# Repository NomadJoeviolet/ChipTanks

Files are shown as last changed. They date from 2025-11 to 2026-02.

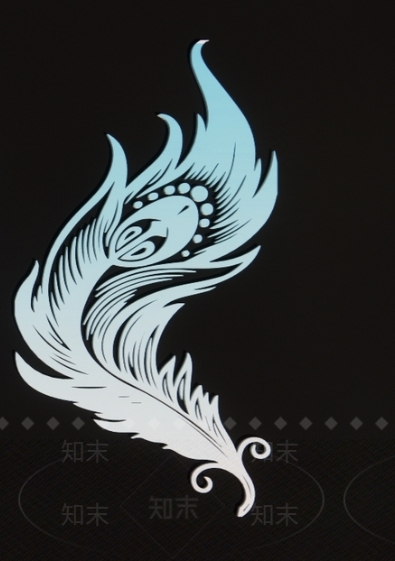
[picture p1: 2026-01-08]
ChipTanksPic/Phoenix.jpg

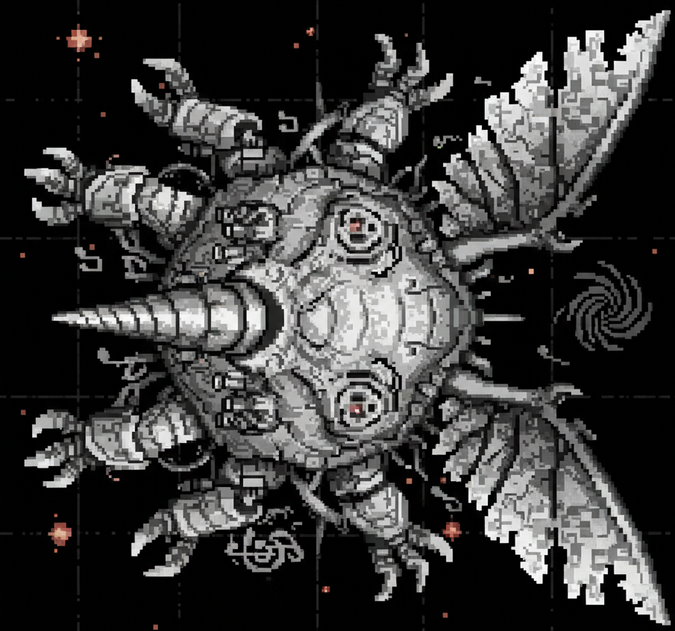
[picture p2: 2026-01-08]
ChipTanksPic/Hundun.png

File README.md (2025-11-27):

# ChipTanks

STM32F103 上的 128×64 OLED 迷你射击游戏。C/C++ 混编，FreeRTOS 驱动，使用 ETL（Embedded Template Library）以适配嵌入式资源约束。

项目总结博客：[ChipTanks-基于C&C++混编的STM32OLED迷你游戏掌机个人项目开发](https://nomadjoeviolet.github.io/p/chiptanks-%E5%9F%BA%E4%BA%8Ecc-%E6%B7%B7%E7%BC%96%E7%9A%84stm32oled%E8%BF%B7%E4%BD%A0%E6%B8%B8%E6%88%8F%E6%8E%8C%E6%9C%BA%E4%B8%AA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)

## 特性概览
- Roguelike 构筑：关卡/波次推进，中场与过关选卡，增益直接作用玩家数据。
- 实体系统：角色与子弹分层，统一管理器调度（行动 → 状态 → 清理 → 渲染）。
- 计时与节奏：用统一步长控制冷却、热量、回血、过场窗口，确定性强。
- 资源友好：固定容量容器（etl::vector），全局 new/delete 重定向至 FreeRTOS 堆。

## 目录结构（摘）
- App/
  - gameEntityManager.hpp（实体管理器）
  - gamePerkCardManager.hpp（选卡/增益管理器）
  - gameProgressManager.hpp（关卡/波次/Boss/过场）
  - threads.cpp（渲染/输入/控制三线程）
  - Bullet/（子弹抽象与实现）
  - Role/（玩家/敌人/基类实现）
  - Data/basicData.hpp（核心数据结构）
- Core/（HAL、FreeRTOS glue 等）
- Drivers/（STM32 HAL、CMSIS）
- Lib/etl/（Embedded Template Library）
- Middlewares/Third_Party/FreeRTOS/
- cmake/（ARM 工具链文件等）

## 构建
前置：
- ARM 交叉工具链（arm-none-eabi-gcc 系）
- CMake（建议 3.20+）与 Ninja（可选）

示例（PowerShell）：
```powershell
# Release 构建
cmake -S . -B build/Release -G Ninja `
  -DCMAKE_TOOLCHAIN_FILE=cmake/gcc-arm-none-eabi.cmake `
  -DCMAKE_BUILD_TYPE=Release
cmake --build build/Release

# Debug 构建
cmake -S . -B build/Debug -G Ninja `
  -DCMAKE_TOOLCHAIN_FILE=cmake/gcc-arm-none-eabi.cmake `
  -DCMAKE_BUILD_TYPE=Debug
cmake --build build/Debug
```
如使用 IDE/调试器：仓库根目录含有若干 .jdebug 文件，可按本地调试环境导入使用。

## 烧录与运行
- 烧录方式取决于本地工具链（如 J-Link、OpenOCD、IDE 内置烧录）。
- 上电后，显示开场动画 → 进入第一关。玩家存活则推进波次/关卡；清场时触发选卡或进入 Boss/通关流程。

## 运行机制
- 线程
  - 渲染线程：根据状态绘制开场/通关/Boss/选卡/战斗界面，控制刷新节奏。
  - 输入线程：按键扫描；战斗态写入玩家移动；选卡态移动光标并确认选择。
  - 控制线程：推进进度（清场→波次/关卡/选卡），调度实体行动/状态，清理无效对象。
- 管理器
  - 实体管理器：
    - addRole/addBullet，updateAllRolesActions/State，updateAllBulletsActions/State
    - 碰撞（AABB）与范围伤害，经验结算与资源回收，drawAllRoles/Bullets
  - 进度管理器：
    - 清场判定（场上仅玩家）→ 波次/关卡推进 → 敌人阵型或 Boss 生成 → 过场与展示
  - 卡片管理器：
    - 初始化仓库、随机抽取、应用所选、未选回库、绘制选卡界面

## 玩法与数值（摘）
- 子弹类型：
  - 普通弹：基础直击伤害。
  - 火球弹：直击后附带圆形范围溅射。
  - 闪电链：穿透，按伤害倍率与常数加成计算。
- 计时器：
  - 射击冷却：归零前禁射；步长与速度决定射速。
  - 热量系统：每次开火升温，周期降温；过热禁射。
  - 回血：累计到阈值离散恢复，直至上限。

## 开发要点
- FreeRTOS 头文件顺序：需先包含 FreeRTOS.h，再包含 task.h（管理器中已按此顺序）。
- 全局 new/delete 重载：见 App/reload_new_delete.cpp（路由至 pvPortMalloc/vPortFree）。
- 容量上限：角色最多 20，子弹最多 100；add 失败时需释放临时对象。
- 清场判定：当前以“容器仅剩玩家”作为清场条件；如引入友军/召唤物，建议改为“无敌方单位”。
- 子弹尺寸：构造子弹时需确保图片与尺寸有效，避免空指针读取尺寸。

## 致谢
- STM32 HAL/FreeRTOS、ETL 以及开源社区相关资源。

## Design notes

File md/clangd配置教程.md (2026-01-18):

# clangd 配置教程（保姆级）

> 适用场景：STM32/嵌入式交叉编译（ARM GCC）、C/C++ 混编、第三方库（如 ETL）大量头文件、Windows + VS Code + clangd 语义分析。
>
> 目标：让 clangd 的“跳转/补全/诊断”与真实编译一致，消灭 `string.h not found`、`type_traits not found`、`Unsupported option '-mcpu=' for target x86_64...`、`unknown type name 'namespace'` 这类“能编译但 clangd 报错”的假红线。

---

## 1. 先搞清楚 clangd 在做什么（核心概念）

clangd 本质是在**模拟编译器**来解析你的代码。

它需要两类信息：

1. **每个源文件实际的编译参数**（include 路径、宏、`-mcpu`、`-std` 等）
   - 最佳来源：`compile_commands.json`（由 CMake/Ninja/Bear 等生成）
2. **工具链自带的系统头/标准库头路径**（如 ARM GCC 的 newlib、libstdc++ 头）
   - clangd 自己猜不准，必须让它能“问”到你的交叉编译器（query-driver）。

如果 clangd 拿不到正确配置，它会退回默认目标（Windows 下常见是 `x86_64-pc-windows-msvc`），然后你就会看到很多“离谱”的报错。

---

## 2. 安装与基本使用（VS Code）

### 2.1 安装 clangd

建议使用：VS Code 扩展 **clangd**（LLVM 官方 clangd 语言服务器的 VS Code 客户端）。

重要提醒：
- 如果你同时装了 MS C/C++ 扩展（cpptools），要注意它可能会提供另一套 IntelliSense。
- 想完全用 clangd：通常做法是**禁用 cpptools 的 IntelliSense**，只保留它的调试/构建能力（可选）。

### 2.2 “怎么确认 clangd 在工作？”

打开 VS Code：
- “输出(OUTPUT)”面板右上角下拉选择 **clangd**
- 你能看到它为哪个文件“Build preamble / publishDiagnostics”等日志。

---

## 3. 必须准备：compile_commands.json

### 3.1 为什么必须要它？

它是“clangd 和真实编译一致”的根基。

没有它，你必须手写一堆 `-I`、`-D`、`-mcpu`，很难维护。

### 3.2 在本项目里它在哪里？

你的工程构建目录里有：
- `build/Debug/compile_commands.json`
- `build/Release/compile_commands.json`

### 3.3 典型坑：Debug/Release 两套数据库

clangd 一次只能用一个 `--compile-commands-dir`。

- 用 Debug 就配 Debug
- 用 Release 就配 Release

---

## 4. VS Code 里配置 clangd（最关键）

clangd 的“启动参数”是最关键入口：`clangd.arguments`。

在项目的：`.vscode/settings.json` 里配置。

### 4.1 我们这次项目最终用的核心参数

（示例：使用 Release 数据库 + ARM GCC 驱动）

```jsonc
{
  "clangd.arguments": [
    "--compile-commands-dir=build/Release",

    // 允许 clangd 调用交叉编译器以获取系统头/标准库头路径
    // 重点：一定要能匹配到 compile_commands.json 里出现的“编译器路径”
    "--query-driver=C:\\INCLUD~1\\Tools\\EMBEDD~1\\ARM-NO~1\\142BCE~1.3RE\\bin\\AR10B2~1.EXE",

    // 允许读取 .clangd 配置文件（建议显式打开）
    "--enable-config",

    // 后台索引
    "--background-index",

    // 排错时用 verbose；稳定后可改回 error
    "--log=verbose"
  ]
}
```

#### 4.1.1 `--query-driver` 的“致命坑”（我们踩过的）

你的 `compile_commands.json` 里编译器是 Windows **8.3 短路径**形式，例如 `AR10B2~1.EXE`。

如果你写成 `arm-none-eabi-g++.exe` 但数据库里实际不是这个路径，clangd 可能不会去 query-driver，于是：
- `<string.h>` / `<type_traits>` 找不到
- 解析崩一片，但工程真实编译没问题

因此：`--query-driver` 要尽量写成“能匹配数据库里真实出现的路径”。

---

## 5. `.clangd` 配置基础（模板 + 解释）

`.clangd` 用来给 clangd **补充/覆盖**编译参数（尤其是“打开某个头文件时没有 compile_commands 条目”的情况）。

> 注意：`.clangd` 不是用来指定 compile_commands 目录的。目录必须用 `--compile-commands-dir`。

### 5.1 通用 `.clangd` 模板（可直接复制）

把它放到项目根目录：`.clangd`

```yaml
CompileFlags:
  Add:
    # 交叉编译目标（避免默认 x86_64 导致 -mcpu 不支持）
    - -target
    - arm-none-eabi

    # MCU/指令集（按你的芯片改）
    - -mcpu=cortex-m3
    - -mthumb

    # 常用工程 include（按项目实际改）
    - -ICore/Inc
    - -IDrivers/CMSIS/Include
    - -IDrivers/CMSIS/Device/ST/STM32F1xx/Include
    - -IDrivers/STM32F1xx_HAL_Driver/Inc

Diagnostics:
  UnusedIncludes: None
  MissingIncludes: None
```

### 5.2 什么时候需要写 `-isystem`？

正常情况下，`--query-driver` 生效后，clangd 会自动得到 ARM GCC 的系统头路径。

如果 query-driver 仍不稳定（或你经常单独打开库头），你可以在 `.clangd` 里额外补 `-isystem`，把 toolchain 的 `include/c++/...` 等路径写进去作为兜底。

---

## 6. 这次最难的坑：ETL 的 `.h` 是 C++，但 clangd 按 C 解析

### 6.1 现象

在 ETL 头里出现：
- `unknown type name 'namespace'`
- `unknown type name 'template'`
- `expected ';' after top level declarator`
- 甚至把 `namespace etl {}` 错误恢复成 `int etl`

并且 clangd 日志出现：
- `Indexing c17 standard library in the context of .../etl/*.h`

这说明 clangd 正在用 **C17（C 语言）**解析这个头。

### 6.2 根因

很多库（ETL 就是典型）大量使用 `.h` 扩展名，但内容是 C++。

clangd 对 `.h` 默认语言判定不总是你期待的：
- 可能按 C 解析
- 可能“借用”某个 `.c` 的编译参数（例如 `-std=gnu11` / `-x c`）来解析头

### 6.3 解决策略（强烈推荐，稳定）

**在 ETL 目录内放一个“就近生效”的 `.clangd`**，让 clangd 在解析 ETL 头时强制 C++。

我们这次最终采用：

1) 在 `Lib/etl/include/etl/.clangd` 放配置

```yaml
CompileFlags:
  Remove:
    - "-std=gnu11"
    - "-std=c11"
    - "-std=gnu99"
    - "-std=c99"
    - "-x"
    - "c"
  Add:
    - "-xc++"
    - "-std=gnu++17"
```

2) 在 `Lib/etl/include/etl/compile_flags.txt` 放 fallback（可选但建议）

```txt
-xc++
-std=gnu++17
```

这两者配合后，你单独打开 ETL 的任何头文件，一般都不会再被当 C。

---

## 7. 我们踩过的坑点总表（对照排错）

### 7.1 `string.h not found`（工程能编译，clangd 报错）

**根因**：clangd 没拿到交叉工具链的系统头路径。

**解决**：
- 配 `--compile-commands-dir=...`
- 配 `--query-driver=...` 并确保能匹配数据库里的编译器路径

### 7.2 `Unsupported option '-mcpu=' for target x86_64-pc-windows-msvc`

**根因**：clangd 回退到 Windows x86_64 目标解析（没有正确使用交叉编译参数）。

**解决**：
- 首先保证 compile_commands 被读取（`--compile-commands-dir`）
- `.clangd` 里兜底加 `-target arm-none-eabi`

### 7.3 `<type_traits>` / C++ 标准库头找不到

**根因**：和 `string.h` 类似，本质还是 query-driver 没生效（或者编译器路径不匹配）。

**解决**：同 7.1。

### 7.4 ETL 报 `namespace` / `template`（最容易误判）

**根因**：头被按 C 解析。

**解决**：同第 6 节，用“就近 `.clangd` + compile_flags”强制 C++。

---

## 8. 保姆级排错流程（以后你自己就能定位）

按顺序做，基本不会走弯路：

1) **看 clangd 日志**（输出面板选择 clangd）
2) 找到你打开的文件对应的日志片段，观察关键字：
   - 是否出现 `Indexing c17 standard library`？（说明它按 C 解析）
   - 是否出现 `Indexing c++ standard library`？（说明它按 C++ 解析）
3) 确认 `compile_commands.json` 是否存在且内容包含该文件
4) 检查 `.vscode/settings.json`：
   - `--compile-commands-dir` 是否指向正确目录
   - `--query-driver` 是否能匹配 compile_commands 里的编译器路径
5) 若是库头（尤其是 `.h` 写 C++）：
   - 在库目录下放“就近 `.clangd`”强制语言
6) 最后手段（兜底）：
   - 在 `.clangd` 里补 `-isystem` 指向工具链头文件路径

---

## 9. 一套通用配置模板（可复制到新项目）

### 9.1 `.vscode/settings.json`（通用）

```jsonc
{
  "clangd.arguments": [
    "--compile-commands-dir=build/Debug",
    "--query-driver=C:\\path\\to\\arm-none-eabi-g++.exe",
    "--enable-config",
    "--background-index",
    "--log=error"
  ]
}
```

### 9.2 项目根 `.clangd`（通用）

```yaml
CompileFlags:
  Add:
    - -target
    - arm-none-eabi
    - -mcpu=cortex-m3
    - -mthumb
    - -ICore/Inc
    - -IDrivers/CMSIS/Include
    - -IDrivers/CMSIS/Device/ST/STM32F1xx/Include
    - -IDrivers/STM32F1xx_HAL_Driver/Inc

Diagnostics:
  UnusedIncludes: None
  MissingIncludes: None
```

### 9.3 “库目录就近 `.clangd`”（当库头是 `.h` 但内容是 C++ 时）

把它放在库头目录（例如 `third_party/foo/include/foo/.clangd`）：

```yaml
CompileFlags:
  Remove:
    - "-std=gnu11"
    - "-std=c11"
    - "-x"
    - "c"
  Add:
    - "-xc++"
    - "-std=gnu++17"
```

---

## 10. 建议的“稳定后收尾”

当一切正常后：
- 把 `--log=verbose` 改回 `--log=error`（减少输出噪声）
- 保持 `--enable-config`（推荐一直开）

---

### 附：常用小贴士

- “报错能编译”的 80% 都是：clangd 没拿到正确的 compile_commands 或 query-driver。
- 看到 `namespace/template` 这类关键字报错，优先怀疑“它按 C 解析了”。
- `.clangd` 规则不生效时，用日志确认它是否启用了 `--enable-config`，以及是否读到了你期望的 `.clangd`。

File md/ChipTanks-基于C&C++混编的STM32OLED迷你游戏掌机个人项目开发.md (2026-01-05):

## 前言
非常适合集成各类库后去雕琢，练习 C&C++混编和设计模式，C++动态内存分配等，很爽的练手项目

仓库：[NomadJoeviolet/ChipTanks: OLED屏幕的Rouglike弹幕射击游戏](https://github.com/NomadJoeviolet/ChipTanks)

项目代码状况
```txt
Top-level groups:
Bullet          Raw=   378 NonEmpty=   304 Code=   266
Data            Raw=   301 NonEmpty=   252 Code=   186
gameEntityManager.hpp Raw=   412 NonEmpty=   362 Code=   300
gamePerkCardManager.hpp Raw=   171 NonEmpty=   145 Code=   128
gameProgressManager.hpp Raw=   410 NonEmpty=   359 Code=   307
Peripheral      Raw=  1624 NonEmpty=  1495 Code=   905
PerkCard        Raw=    67 NonEmpty=    56 Code=    54
reload_new_delete.cpp Raw=    61 NonEmpty=    52 Code=    33
Role            Raw=  3314 NonEmpty=  2865 Code=  2349
threads.cpp     Raw=   259 NonEmpty=   219 Code=   140

Totals: RawLines=6997  NonEmptyLines=6109  CodeLines=4668
```

## 游戏设计
玩法介绍：[ChipTanks-玩法介绍](https://nomadjoeviolet.github.io/p/chiptanks-%E7%8E%A9%E6%B3%95%E4%BB%8B%E7%BB%8D/)

游戏设计：[ChipTanks-游戏设计](https://nomadjoeviolet.github.io/p/chiptanks-%E6%B8%B8%E6%88%8F%E8%AE%BE%E8%AE%A1/)

## 硬件选型
使用的OLED屏的显示驱动为SSD1306
主控板为stm32f103c8t6

## 开发工具链
使用 VSCode+Intellisence+CubeMX+CMake+Ninja+arm-none-eabi+Ozone+Jlink的高自定义开发工具链

代码编辑器采用VSCode，语言服务器使用VSCode的Intellisence来实现智能代码补全和理解功能，用CubeMX生成硬件抽象层代码，CMake和Ninja作为项目构建工具，使用arm-none-eabi编译器，烧录和调试使用Ozone，硬件烧录器使用Jlink

CubeMX使用的版本为`6.15.0`
CMake使用的版本为`4.1.0`
编译器arm-none-eabi使用的版本为`14.3 rel1`

开发方式采用C&C++混编，使用`exter "C" { }`解决C++名词修饰导致C无法链接的问题，`extern "C"`的作用就是告诉C++编译器修改符号表生成方式，将C++符号的生成方式换成了的生成方式。

实践上将FreeRTOS的线程函数入口声明 定义为`As external`



然后在`cpp`文件中去实现，实现的函数用`extern "C"`包裹即可，这样`void keyScanThread(void *argument)`经过C++编译器编译后的符号就可以被C链接

```cpp

#ifdef __cplusplus
extern "C" {
#endif

void keyScanThread(void *argument) {
	for(){
		//...
		osDelay(10);
	}
}

#ifdef __cplusplus
}
#endif

```

## 第三方库引入
引入FreeRTOS和dsp库以及etl库

引入FreeRTOS用来处理多线程任务，引入dsp库用来加速部分运算（主要想用来加速 游戏实体 碰撞检测）（实际基本上没用，当做练手了），引入etl库来做到 零开销的使用 C++ 容器 提高开发效率，其确定性内存管理 (Deterministic Memory)在**栈上**或**静态区**分配固定大小的内存，而不是在堆上动态扩容，能完全避免了内存碎片问题，且内存占用在编译期就是已知的，非常适合 RAM 有限的 STM32，同时有容器去实现设计模式等会更加高效。

## 代码实现
### 动态内存分配在嵌入式平台上的解决
因嵌入式平台的内存资源非常有限，同时还要保证FreeRTOS的线程安全，需要对C++的动态内存分配（`new`和`delete`）进行重载，重载为`pvPortMalloc(size)`和`vPortFree(ptr)`，FreeRTOS线程安全的分配方式，从FreeRTOS的堆里面分配

```cpp
#include "FreeRTOS.h"
#include "task.h" // pvPortMalloc and vPortFree are defined here
#include <stddef.h> // Use C header for size_t in embedded environments
void* operator new(size_t size) {
    void* ptr = pvPortMalloc(size);
    return ptr;
}
void operator delete(void* ptr) noexcept {
    if (ptr) {
        vPortFree(ptr);
    }
}
void* operator new[](size_t size) {
    void* ptr = pvPortMalloc(size);
    return ptr;
}
void operator delete[](void* ptr) noexcept {
    if (ptr) {
        vPortFree(ptr);
    }
}

void operator delete(void* ptr, size_t size) noexcept {
    (void)size; // The size parameter is often unused in custom deallocations.
    if (ptr) {
        vPortFree(ptr);
    }
}
void operator delete[](void* ptr, size_t size) noexcept {
    (void)size;
    if (ptr) {
        vPortFree(ptr);
    }
}
```

这样重载后，动态分配的内存不会从 系统堆里面分配，而是从FreeRTOS的 **静态 堆**（内存池） （此处静态指 编译期最大容量确定）里面分配，从而避免可能的堆栈溢出，FreeRTOS的堆栈管理方案采用 安全 且 有高效内存碎片化处理 的heap4 即可



**为什么不使用系统堆？**
1. 因为在嵌入式实时操作系统中，调用C标准库中 malloc() 和 free() 是危险的，C++中的 new 和 delete 也一样：
2.  这些函数在小型嵌入式系统中并不总是可用的，小型嵌入式设备中的RAM不足。
3.  它们的实现可能非常的大，占据了相当大的一块代码空间。
 4. 他们几乎都不是线程安全的。
 5. 它们并不是确定的，每次调用这些函数执行的时间可能都不一样。
 6. 它们有可能产生内存碎片。
 7. 这两个函数会使得链接器配置得复杂。

系统内存分配




由此可以直接看出重载后动态内存分配可以保证系统栈和线程的安全

### 项目文件结构
#### 整体结构
```txt
ChipTanks/
├── App/                        // 游戏应用逻辑层
│   ├── Bullet/                 // 子弹模块
│   ├── Data/                   // 基础数据定义
│   ├── Peripheral/             // 外设驱动（OLED, KEY）
│   ├── PerkCard/               // 天赋卡片模块
│   ├── Role/                   // 角色模块（玩家与敌人）
│   ├── gameEntityManager.hpp   // 实体管理器
│   ├── gamePerkCardManager.hpp // Perk管理器
│   ├── gameProgressManager.hpp // 进度管理器
│   ├── reload_new_delete.cpp   // 内存管理重载
│   └── threads.cpp             // FreeRTOS任务定义
├── ChipTanksPic/               // 项目图片资源（可能为空或存放设计图）
├── Core/                       // STM32CubeMX 生成的核心代码
│   ├── Inc/                    // 核心头文件 (main.h, FreeRTOSConfig.h 等)
│   └── Src/                    // 核心源文件 (main.c, freertos.c, stm32f1xx_it.c 等)
├── Drivers/                    // 硬件驱动库
│   ├── CMSIS/                  // ARM Cortex 微控制器软件接口标准
│   │   ├── Core/               // 核心外设访问层
│   │   ├── DSP/                // 数字信号处理库 (DSP Lib)
│   │   └── ...
│   └── STM32F1xx_HAL_Driver/   // STM32F1系列 HAL 库驱动
├── Lib/                        // 第三方库
│   └── etl/                    // Embedded Template Library (嵌入式模板库)
├── Middlewares/                // 中间件
│   └── Third_Party/
│       └── FreeRTOS/           // FreeRTOS 实时操作系统源码
├── build/                      // 编译输出目录 (Debug/Release)
├── cmake/                      // CMake 构建脚本与工具链配置
├── CMakeLists.txt              // 项目根 CMake 配置文件
└── STM32F103C8Tx_FLASH.ld      // 链接脚本
```

#### App结构
```txt
ChipTanks/App
├── gameEntityManager.hpp       // 游戏实体管理器（管理所有角色和子弹）
├── gamePerkCardManager.hpp     // Perk卡片管理器（管理升级抽卡逻辑）
├── gameProgressManager.hpp     // 游戏进度管理器（管理关卡流程）
├── reload_new_delete.cpp       // 重载C++内存分配（适配FreeRTOS）
├── threads.cpp                 // FreeRTOS任务定义与调度
├── Bullet/                     // 子弹模块
│   ├── bullet.cpp              // 子弹逻辑实现
│   └── bullet.hpp              // 子弹基类与派生类定义
├── Data/                       // 数据模块
│   └── basicData.hpp           // 基础数据结构与枚举定义
├── Peripheral/                 // 外设驱动模块
│   ├── KEY/
│   │   ├── key.cpp             // 按键扫描实现
│   │   └── key.hpp             // 按键接口定义
│   └── OLED/
│       ├── font.c              // 字库数据
│       ├── font.h              // 字库声明
│       ├── oled.c              // OLED驱动实现
│       └── oled.h              // OLED接口定义
├── PerkCard/                   // 天赋卡片模块
│   └── prekCard.hpp            // Perk卡片类定义
└── Role/                       // 角色模块
    ├── enemyRole.cpp           // 敌人逻辑实现
    ├── enemyRole.hpp           // 敌人派生类定义
    ├── leadingrole.cpp         // 主角逻辑实现
    ├── leadingRole.hpp         // 主角派生类定义
    ├── role.cpp                // 角色基类逻辑实现
    └── role.hpp                // 角色基类定义
```
### 架构与设计思路
主要采用 **面向对象（OOP）** 的设计思路，结合FreeRTOS实时操作系统，构建简单的嵌入式游戏框架。

主要分为5各层级：
1. 硬件抽象层：基于HAL库的对底层硬件的抽象，对外设硬件操作进行再次封装
2. 核心数据层（Data）：定义游戏通用的数据结构和枚举
3. 游戏实体层（Entity/Role）：定义角色(Role)基类和子弹(Bullet)基类 及其派生类
4. 管理器层（Manager）：负责实体生命周期管理，碰撞检测，进度控制和PerkSelection系统
5. 应用逻辑层（App Logic）：多线程任务处理，游戏业务逻辑

#### 硬件抽象层
在HAL库基础上，对外设进行面向对象的进一步封装

 **OLED**(使用的keysking的开源库):
     提供OLED_DrawImage，OLED_PrintString 等绘图 API。
     包含字库 (`font.c`)，支持文本显示。
     作为游戏的**输出设备**，负责将游戏状态可视化。
 **KEY**:
     提供按键扫描逻辑。
     作为游戏的**输入设备**，将物理按键映射为游戏内的控制信号

#### 核心数据层
 定义了所有游戏实体共用的数据结构，如 `HealthData`（血量）、`AttackData`（攻击）、`SpatialData`（位置与大小）、`HeatData`（热量）等。
 使用 `struct` 组合数据，便于在不同类之间传递和管理状态。
 定义了 `RoleIdentity`（身份）、（子弹类型）等关键枚举。
#### 游戏实体层
这是游戏逻辑的核心部分，采用了**继承与多态**的设计。
 ##### **基类设计**:
**`IRole` （role.hpp**）: 所有角色（玩家和敌人）的基类。包含 `RoleData` 指针，管理角色的所有属性。
定义了虚函数接口：`init()`, `think()`, `doAction()`, `drawRole()`, `die()`, `shoot()`。
实现了通用的物理逻辑：`move()`（移动与边界检查）、`update()`（状态更新）、`createBullet()`。

**`IBullet` (bullet.hpp)**: 所有子弹的基类。
定义了 `move()`, `update()`, `drawBullet()`, `die()` 等接口。
 ##### **派生类设计**:
**`LeadingRole` (`leadingRole.cpp`)**: 玩家控制的主角。
实现了复杂的升级逻辑 (`levelUp`)、热量控制和多武器切换。
单例模式或全局对象管理（通常作为唯一主角存在）。

**`EnemyRole` (`enemyRole.hpp`)**: 各种敌人的实现。
**`FeilianEnemy`**: 高速骚扰型，只发普通弹。
**`TaotieEnemy`** (BOSS): 状态机控制的复杂行为（吞噬、冲撞）。
**`XiangliuEnemy`** (BOSS): 召唤与全屏弹幕。

**`BasicBullet` / `FireBallBullet` / `LightningLineBullet`**: 不同类型的子弹实现，具有不同的伤害逻辑和特效。

#### 管理器层

##### 1.**`GameEntityManager` (`gameEntityManager.hpp`)**:
 核心职责:
	  维护所有活跃的角色和子弹容器，使用固定容量的嵌入式向量。包含角色池（最多20个）和子弹池（最多100个），以及游戏结束标记。提供注册新增实体、分阶段的行为与状态更新、碰撞与范围伤害检测、统一渲染、失效实体清理、获取主角指针和经验投递等功能。行为与状态分离，更新顺序通常为：角色行为、子弹行为、角色状态、子弹状态、清理、渲染。碰撞使用轴对齐包围盒，子弹碰撞允许穿透；范围伤害使用圆形距离判定。所有容器操作使用临界区保护以确保一致性。
```cpp
	etl::vector<IRole *, 20>    m_roles;   //角色池，存放所有角色指针
    etl::vector<IBullet *, 100> m_bullets; //子弹池，存放所有子弹指针
```

功能:
1. `addRole()`, `addBullet()`: 注册新实体。
2. `updateAllRolesActions()`: 每帧调用所有角色的 `doAction()`。
3. `updateAllRolesState()`：每帧调用所有角色的 `update()`。 
4. `checkxxxxCollision()`: 进行碰撞检测（AABB 碰撞盒），处理伤害结算。
5. `drawAllRoles()`和`drawAllBullets`: 统一渲染所有实体。
6. `cleanUpInvalidRoles()`和`cleanupInvalidBullets()`: 回收非活跃实体的内存，处理主角经验值获取。
7. `getPlayerRole()`：获取主角的指针

##### 2.`GamePerkCardManager` (`gamePerkCardManager.hpp`)
核心职责：
	管理 Rogue-like 的随机强化流程，包括卡片仓库管理、抽取待选卡、选择应用以及未选卡回库。使用两个固定容量的嵌入式向量存储卡片仓库与选卡槽，并维护选卡状态、选中索引与数量。初始化时按配置表生成卡片；触发选卡会随机抽取最多三张并进入选卡状态；选择后将效果应用到玩家（如提高生命、攻击、攻速、移动速度、散热效率，或解锁火球与闪电，或提升范围与伤害倍率），随后将未选卡退回仓库并退出选卡状态。选卡界面显示卡名并有选中指示器。
    
```cpp
etl::vector<PerkCard, MAX_CARD_COUNT>       m_cardWarehouse;  // 卡片仓库（存所有卡片）
etl::vector<PerkCard, SELECTION_SLOT_COUNT> m_selectionSlots; // 选卡槽（临时存3张待选）
```

 功能
1. `initWarehouse()`：初始化卡片仓库
2. `triggerPerkSelection()`：触发`PerkSelection`
3. `selectCard`：选择卡片，同时将卡片效果应用
4. `drawSelectionUI`：绘制选卡界面的UI

##### 3.`GameProgressManager` (`gameProgressManager.hpp`)
核心职责：
	控制游戏整体流程，包括关卡推进、波次刷新、Boss 触发与展示、胜利/失败判定，以及开场/通关/警告等过场的展示与计时。与实体管理器和卡片管理器协作，驱动每一波敌人生成与选卡节点的触发。
功能
1. `resetGameProgress()`：重置整局流程，创建玩家实体并加入实体管理器，初始化卡片管理器仓库
2. `updateGameProgress()`：推进波次/关卡与选卡触发，特定条件调用 `AddWaveEnemies()` 生成新的一波敌人
3. `AddWaveEnemies()`：根据当前关卡与波次生成敌人阵型或 Boss
4. `drawOpeningCG()`：绘制开场过场动画
5. `drawClearCG()`：绘制通关动画
6. `drawShowBoss()`：绘制 Boss 海报或挑战警告
#### 应用逻辑层
`threads.cpp`: 有三个核心任务线程来驱动整体逻辑

 `oledTaskThread`: 负责渲染时序。根据状态（开场、通关、Boss 展示、选卡、正常战斗）选择对应绘制路径；最终输出帧并控制刷新频率。
 `keyScanThread`: 负责输入采集与分发。非选卡状态下更新玩家动作（上下左右）；选卡状态下移动 UI 光标并执行选中操作；根据游戏/过场状态决定是否响应按键。
 `gameControlThread`: 负责主控流程与核心时序。Game Over 时重置游戏；正常状态下在非选卡与非过场时推进进度、执行实体行为与状态更新、清理无效实体。

### 各层级和功能的代码实现与解析

#### 硬件抽象层 
##### KEY

当前按键采用“左右各 4 独立键，低电平按下”方案，不再是 4x4 矩阵。CubeMX 已将引脚配置为上拉输入，扫描直接读电平即可。左右各有独立状态缓存，方向枚举在上层做映射。

```cpp
#ifndef KEY_HPP
#define KEY_HPP

#include "gpio.h"

typedef struct {
    GPIO_TypeDef* GPIOx;
    uint16_t GPIO_Pin;
} KeyGPIO;

enum class LeftKeyState {
    KEY_DOWN = 0,
    KEY_UP   = 1,
    KEY_RIGHT= 2,
    KEY_LEFT = 3
};

enum class RightKeyState {
    KEY_DOWN = 0,
    KEY_LEFT = 1,
    KEY_RIGHT= 2,
    KEY_UP   = 3
};

class Key {
public:
    uint8_t m_leftKeyButton[4]  = {0}; // 左手4键，低电平按下
    uint8_t m_rightKeyButton[4] = {0}; // 右手4键，低电平按下
    KeyGPIO* m_rightInput = nullptr;
    KeyGPIO* m_leftInput  = nullptr;
public:
    Key(KeyGPIO* rightInput, KeyGPIO* leftInput)
        : m_rightInput(rightInput), m_leftInput(leftInput) {}
    ~Key() {};

    void init() {
        // 引脚已在 MX_GPIO_Init 配为上拉输入，无需重复配置
    }

    void scan() {
        for (uint8_t i = 0; i < 4; i++) {
            m_rightKeyButton[i] = (HAL_GPIO_ReadPin(m_rightInput[i].GPIOx, m_rightInput[i].GPIO_Pin) == GPIO_PIN_RESET);
        }
        for (uint8_t i = 0; i < 4; i++) {
            m_leftKeyButton[i]  = (HAL_GPIO_ReadPin(m_leftInput[i].GPIOx,  m_leftInput[i].GPIO_Pin)  == GPIO_PIN_RESET);
        }
    }
};

extern Key key;
#endif // KEY_HPP
```

```cpp
#include "key.hpp"

KeyGPIO keyRightOutput[4] = {
    {KEY_R1_GPIO_Port, KEY_R1_Pin},
    {KEY_R2_GPIO_Port, KEY_R2_Pin},
    {KEY_R3_GPIO_Port, KEY_R3_Pin},
    {KEY_R4_GPIO_Port, KEY_R4_Pin}
};

KeyGPIO keyLeftInput[4] = {
    {KEY_C1_GPIO_Port, KEY_C1_Pin},
    {KEY_C2_GPIO_Port, KEY_C2_Pin},
    {KEY_C3_GPIO_Port, KEY_C3_Pin},
    {KEY_C4_GPIO_Port, KEY_C4_Pin}
};

Key key(keyRightOutput, keyLeftInput);

```

##### OLED
使用的是keysking的开源，该代码中提供OLED的驱动和绘画渲染的API，直接使用即可

#### 核心数据层
**概览**
 定义了游戏所需的基础数据类型：身份、子弹类型、动作/移动/攻击/死亡/空间等数据结构，以及角色与子弹的数据聚合体。
 “纯数据载体”，不含行为方法；行为由上层实体类与管理器驱动。
 时间与数值单位采用“毫秒 + 小整型”为主，满足嵌入式 MCU 资源约束。
**枚举类型**
 `RoleIdentity`: 标识阵营与身份（UNKNOWN/ENEMY/Player）。用于伤害互斥、经验结算等。
 ```cpp
  enum class RoleIdentity {
    UNKNOWN = 0,
    ENEMY   = 1,
    Player  = 2,
};
  ```
 
 `BulletType`: 子弹种类（BASIC/FIRE_BALL/LIGHTNING_LINE）。影响碰
 撞、穿越、范围与倍率等期望行为。
```cpp
enum class BulletType {
    BASIC          = 0,
    FIRE_BALL      = 1,
    LIGHTNING_LINE = 2,
};
```

 `ActionState`: 动作态（IDLE/MOVING/ATTACKING）。由输入或 AI 控制，驱动移动/攻击决策。
```cpp
enum class ActionState { IDLE = 0, MOVING = 1, ATTACKING = 2 };
```
 
 `AttackMode`: 预留的攻击形态枚举（MODE_1…MODE_6），可用于多段或多式攻击切换。
 ```cpp
 enum class AttackMode { NONE = 0, MODE_1 = 1, MODE_2 = 2, MODE_3 = 3 , MODE_4 = 4 , MODE_5 = 5 , MODE_6 = 6 };
 ```
 
 `MoveMode`: 移动方向（NONE/UP/DOWN/LEFT/RIGHT）。
 `CollisionDirection`: 碰撞方向（NONE/LEFT/RIGHT/UP/DOWN），供状态响应/回退使用。
```cpp
enum class MoveMode { NONE = 0, UP = 1, DOWN = 2, LEFT = 3, RIGHT = 4 };
```

**HeatData（热量数据）**
 变量：`currentHeat`，`maxHeat`，`heatCoolDownRate`，`heatCoolDownTimer`，`heatPerShot`。
 构造：可用构造函数设置“初值、上限、冷却速率、每枪增量”。默认不显式初始化 `heatCoolDownTimer`（保持 0 即可）。
 用法：开火前检查 `currentHeat + heatPerShot <= maxHeat`；每帧/每周期按 `heatCoolDownRate` 降温（受 `heatCoolDownTimer` 和节拍控制）。
```cpp
class HeatData {
public:
    uint8_t currentHeat{};
    uint8_t maxHeat{};
    uint8_t heatCoolDownRate{};
    uint8_t heatCoolDownTimer{};
    uint8_t heatPerShot{};
public:
    HeatData() = default;
    HeatData(uint8_t current, uint8_t max, uint8_t coolDownRate, uint8_t perShot)
    : currentHeat(current)
    , maxHeat(max)
    , heatCoolDownRate(coolDownRate)
    , heatPerShot(perShot) { }
};
```

**HealthData（生命与回复）**
 变量：`currentHealth`，`maxHealth`，`healValue`，`healTimeCounter`，`healResetTime`，`healSpeed`。
 语义：每 `healResetTime / healSpeed` 毫秒回复 `healValue` 点；`healTimeCounter` 为内部累加计时。
 默认值：最大/当前 100，`healValue=3`，`healResetTime=15000ms`，`healSpeed=5`（等效更高频率）。
 ```cpp
// 血量数据结构体
// 每隔一段时间自动回复一定量的血量
// 每 healResetTime/healSpeed 毫秒回复 healValue 点血量
class HealthData {
public:
    uint16_t currentHealth{};
    uint16_t maxHealth{};
    uint8_t  healValue       = 3;
    uint16_t healTimeCounter = 0;
    uint16_t healResetTime   = 15000;
    uint8_t  healSpeed       = 5;
};
 ```

**SpatialMovementData（空间与移动）**
 变量：`canCrossBorder`，`consecutiveCollisionCount`，`moveSpeed`（int8），`currentPosX/Y`，`refPosX/Y`，`sizeX/Y`。
 构造：可一次性设置“是否可越界、速度、当前位置/参考位置、尺寸”。
 语义：
     `currentPos`：实际显示/碰撞后的生效位置。
     `refPos`：预期位置（用于先计算再做碰撞回退）。
     `consecutiveCollisionCount`：连续碰撞计数，可用于卡边/弹跳等处理。
     `canCrossBorder`：是否允许越界飞行（闪电线之类特种弹可开启）。
```cpp
/**
 * @brief 空间移动数据结构体
 * @note  包含位置尺寸和移动速度
 * @param moveSpeed 移动速度
 * @param currentPosX 初始X位置，是物体左上角的X坐标
 * @param currentPosY 初始Y位置，是物体左上角的Y坐标
 * @param refPosX 参考X位置，用于碰撞检测后的回退
 * @param refPosY 参考Y位置，用于碰撞检测后的回退
 * @param sizeX 宽度
 * @param sizeY 高度
 */
class SpatialMovementData {
public:
    //能否穿越边界
    bool canCrossBorder = false;
    //连续触发碰撞次数（用来碰撞检测后的处理）
    uint8_t consecutiveCollisionCount = 0;
    //移动速度
    int8_t moveSpeed{};
    //位置尺寸
    int16_t currentPosX{};
    int16_t currentPosY{};
    int16_t refPosX{};
    int16_t refPosY{};
    uint8_t sizeX{};
    uint8_t sizeY{};
public:
    SpatialMovementData() = default;
    /**
     * @brief 构造函数
     * @param speed 移动速度，可以取负值表示反方向移动
     * @param currentPosX 现在X位置
     * @param currentPosY 现在Y位置
     * @param refPosX 期望X位置
     * @param refPosY 期望Y位置
     * @param sx 宽度
     * @param sy 高度
     */
    SpatialMovementData(
        bool canCrossBorder, int8_t speed, uint8_t currentPosX, uint8_t currentPosY, uint8_t refPosX, uint8_t refPosY,
        uint8_t sx, uint8_t sy
    )
    : canCrossBorder(canCrossBorder)
    , moveSpeed(speed)
    , currentPosX(currentPosX)
    , currentPosY(currentPosY)
    , refPosX(refPosX)
    , refPosY(refPosY)
    , sizeX(sx)
    , sizeY(sy) { }
};
```

**RoleAttackData（攻击参数）**
 字段：`shootSpeed`，`shootCooldownTimer`，`shootCooldownResetTime`，`shootCooldownSpeed`，`attackPower`，`collisionPower`，`bulletSpeed`，`bulletRange`，`bulletDamageMultiplier`。
 语义：
     冷却体系：开火将 `shootCooldownTimer` 置为 `shootCooldownResetTime`，随后按帧减速（受 `shootCooldownSpeed` 影响）；计时至 0 才可再开火。
     `attackPower`：子弹/技能的基础伤害。
     `collisionPower`：实体体撞造成的伤害。
     `bulletSpeed`/`bulletRange`/`bulletDamageMultiplier`：子弹飞行速度、范围（火球类有效）、伤害倍率（闪电链类有效）。
```cpp
class RoleAttackData {
public:
    //攻击速度
    uint8_t  shootSpeed;
    uint16_t shootCooldownTimer;
    uint16_t shootCooldownResetTime;
    uint8_t  shootCooldownSpeed;
    //攻击力
    uint8_t attackPower;
    uint8_t collisionPower;
    //子弹速度
    int8_t bulletSpeed;
    //子弹伤害范围
    uint8_t bulletRange;//只对火球弹生效
    //子弹伤害倍率
    float bulletDamageMultiplier;//只对闪电链弹生效
};
```

**InitData（初始化）**
 变量：`isInited`，`posX/posY`，`init_count`。
 用法：实体首次加入场景时从此读取出生点/初始状态；`isInited`控制是否进入正常逻辑。

**ActionData（动作控制）**
 变量：`currentState`，`attackMode`，`moveMode`。
 用法：由输入或 AI 写入；逻辑层依据其驱动运动与攻击。

**DeathData（死亡信息）**
 变量：`isDead`，`deathTimer`（默认 500ms），`dropExperiencePoints`。
 用法：死亡后倒计时播放动画；清理阶段根据阵营发经验（由管理器处理）。

**RoleData（角色聚合体）**
 聚合：`InitData`、`RoleIdentity`、`isActive`、`DeathData`、`ActionData`、`HealthData`、`level`、`HeatData`、`RoleAttackData`、`SpatialMovementData`、`img`。
 默认构造初始化要点：
     身份 UNKNOWN、`isActive=false`、`level=1`。
     生命/热量/攻击参数设了合理初值：最大生命 100；热量上限 100、每枪+10、冷却速率 10；冷却重置 1000ms；攻 10/撞 5；子弹速度 1；火球范围 1；闪电倍率 1.5。
     空间数据初始移动速度 1，位置/尺寸 0。
     `img=nullptr`（注释明确“此处易出错，若有问题优先检查”）。
 典型交互：
     管理器在更新状态前用 `refPos` 做碰撞探测，结果再更新 `currentPos`。
     玩家升级逻辑在管理器的状态更新阶段主动调用（基于 `experiencePoints` 等外部字段，非此处）。
     Perk 卡片直接修改 `RoleData`内子段（例如血量上限、射速、热量、移动等）。
```cpp
class RoleData {
public:
    //初始化位置
    InitData initData;
    //基本信息
    RoleIdentity identity;
    bool         isActive = false;
    //死亡状态信息
    DeathData deathData;
    //动作信息
    ActionData actionData;
    //血量信息
    HealthData healthData;
    //等级信息
    uint8_t level;
    //热量信息
    HeatData heatData;
    //攻击信息
    RoleAttackData attackData;
    //空间移动信息
    SpatialMovementData spatialData;
    //图片信息
    const Image *img = nullptr; //易出错的地方，有问题优先检查
    //角色图片，指向同一片内存，利用浅拷贝的特性
public:
    RoleData() {
        identity = RoleIdentity::UNKNOWN;
        //初始化信息
        initData.posX       = 0;
        initData.posY       = 0;
        initData.init_count = 0;
        //血量信息初始化
        healthData.currentHealth   = 100;
        healthData.maxHealth       = 100;
        healthData.healValue       = 3;
        healthData.healTimeCounter = 0;
        healthData.healResetTime   = 15000;
        healthData.healSpeed       = 5;
        //等级初始化
        level = 1;
        //热量信息初始化
        heatData = HeatData(0, 100, 10, 10);
        //射击后，cooldown计时器增加，只有当计时器达到0时才能再次射击
        attackData.shootSpeed             = 5;
        attackData.shootCooldownTimer     = 0;
        attackData.shootCooldownSpeed     = 5;
        attackData.attackPower            = 10;
        attackData.collisionPower         = 5;
        attackData.shootCooldownResetTime = 1000; // Added initialization for shootCooldownResetTime
        //子弹速度
        attackData.bulletSpeed            = 1;
        //火球弹伤害范围
        attackData.bulletRange            = 1;
        //闪电链伤害倍率
        attackData.bulletDamageMultiplier = 1.5f;
        //空间移动信息初始化
        spatialData = SpatialMovementData(0, 1, 0, 0, 0, 0, 0, 0);
        //死亡状态信息初始化
        deathData.deathTimer = 500;
        deathData.isDead     = false;
        deathData.dropExperiencePoints = 0;
        //图片信息初始化
        img = nullptr;
    }
};
```

**BulletData（子弹聚合体）**
 聚合：`fromIdentity`（默认 UNKNOWN）、`DeathData`、`SpatialMovementData`、`damage`、`range`、`type`、`isActive`、`img`。
 构造函数（重载二）：
     默认构造：不做初始化。
     参数构造：
         参数：`speed`，`currentPosX/Y`，`dmg`，`rg`，`type`，`dmgMultiplier=1.0f`。
         逻辑：按 `type` 分支设置 `damage`、`spatialData`、`isActive=true`、`range=rg`；`LIGHTNING_LINE` 设为 `canCrossBorder=true`。
```cpp
class BulletData {
public:
    //来自
    RoleIdentity fromIdentity{RoleIdentity::UNKNOWN};
    //死亡信息
    DeathData deathData;
    //空间移动信息
    SpatialMovementData spatialData;
    //伤害值
    uint8_t damage{};
    uint8_t range{};
    //子弹类型
    BulletType type{};
    //是否激活
    bool isActive{true};
    //图片信息
    const Image *img = nullptr;
public:
    BulletData() = default;
    BulletData(int8_t speed, uint8_t currentPosX, uint8_t currentPosY, uint8_t dmg, uint8_t rg, BulletType type , float dmgMultiplier = 1.0f) {
        //根据类型进行初始化
        this->type = type;
        switch (this->type) {
        case BulletType::BASIC:
            //img = &bulletImg;
            damage = dmg;
            spatialData =
                SpatialMovementData(false, speed, currentPosX, currentPosY, currentPosX, currentPosY, img->w, img->h);
            isActive = true;
            range    = rg;
            break;
        case BulletType::FIRE_BALL:
            //img = &fireBallImg;
            damage = dmg;
            spatialData =
                SpatialMovementData(false, speed, currentPosX, currentPosY, currentPosX, currentPosY, img->w, img->h);
            isActive = true;
            range    = rg;
            break;
        case BulletType::LIGHTNING_LINE:
            //img = &lightningLineImg;
            damage = dmg;
            spatialData =
                SpatialMovementData(true, speed, currentPosX, currentPosY, currentPosX, currentPosY, img->w, img->h);
            isActive = true;
            range    = rg;
            break;
        }
    }
};
```

#### 游戏实体层
实体层以抽象的角色基类为核心，所有角色共享一套数据驱动的状态与行为流程：初始化、决策、执行、推进与渲染。

玩家与敌人分别在其派生类中实现具体的思考与行动——玩家由输入驱动，敌人由定时与模式切换驱动。当角色需要开火时，通过角色基类提供的子弹工厂按类型生成不同机制的弹药：普通弹以基础伤害直击，火球弹在直击之外叠加范围溅射，闪电链以倍数加成的穿透伤害形成压制。

角色推进采用“参考位置 + 碰撞回退”的模式：先根据移动意图计算参考坐标，再用轴对齐包围盒检测并按碰撞方向和连续碰撞次数逐步回退，避免卡边。

数值系统围绕冷却、热量和回血三条独立的时序通道运行：冷却按步长与速度递减至零方可再次射击，热量每固定周期按散热速率衰减，回血以计时器触发离散恢复。

所有实体的创建、更新、碰撞与回收由实体管理器统一编排，管理器在行为与状态阶段之间明确分离职责：先让角色与子弹各自做决策与动作，再推进位置与伤害结算，随后清理失效对象并为玩家结算经验，最后渲染画面。

整体以固定容量的嵌入式容器与临界区保护保证在资源受限与多任务环境下的确定性与安全性，同时通过将机制落在数据结构上，保留足够的可调性与扩展空间。

```cpp
#ifndef ROLE_HPP
#define ROLE_HPP

#include "basicData.hpp"
#include "bullet.hpp"
#include "etl/algorithm.h"

extern uint8_t controlDelayTime ;
/**
 * @brief 角色接口类
 * @note 所有角色类均需继承该接口类
 * @note think()函数用于实现AI逻辑，决定Action状态
 */
class IRole {
protected:
    RoleData* m_pdata = nullptr ;
public:
    IRole()  {
        if(m_pdata == nullptr)
            m_pdata = new RoleData();
    }
    virtual ~IRole() {
        if(m_pdata != nullptr)
            delete [] m_pdata;
        m_pdata = nullptr;
    }
public:
    RoleData* getData() {
        return m_pdata;
    }
    virtual void shoot(uint8_t x , uint8_t y , BulletType type) = 0;
    virtual void doAction() = 0;
    virtual void init() = 0;
    virtual void die() = 0;
    virtual void think() = 0;
    virtual void drawRole() = 0; // 画角色函数声明
    IBullet* createBullet(uint8_t x , uint8_t y , BulletType type ) ;
    void move(int8_t dirX, int8_t dirY , bool ignoreSpeed  = false) ;
    void update(CollisionResult collisionResult) ;
    void takeDamage(uint8_t damage) ;
    bool isActive() ;
};
#endif // ROLE_HPP
```

实现上仅重点展示`update()`函数，该函数会在`GameEntityManager`中调用，

```cpp
void IRole::update(CollisionResult collisionResult) {
    //初始化
    if (!m_pdata->initData.isInited) {
        //首次初始化
        init();
        return;
    }
    if (m_pdata->deathData.isDead) {
        die();
        return;
    }
    //位置更新
    if (!collisionResult.isCollision) {
        m_pdata->spatialData.currentPosX = m_pdata->spatialData.refPosX;
        m_pdata->spatialData.currentPosY = m_pdata->spatialData.refPosY;
    } else {
        m_pdata->spatialData.refPosX = m_pdata->spatialData.currentPosX;
        m_pdata->spatialData.refPosY = m_pdata->spatialData.currentPosY;
    }
    //碰撞处理
    //碰撞处理在位置更新后进行
    if (collisionResult.isCollision) {
        //用来避免单次碰撞一次退回的无法解决碰撞的问题
        m_pdata->spatialData.consecutiveCollisionCount++;
        //碰撞后退回
        uint8_t backStep = 2*m_pdata->spatialData.consecutiveCollisionCount ;
        if (m_pdata->identity == RoleIdentity::Player) backStep = 5*m_pdata->spatialData.consecutiveCollisionCount ;
        if (collisionResult.direction == CollisionDirection::LEFT)
            m_pdata->spatialData.refPosX = etl::max(m_pdata->spatialData.refPosX - backStep, 0);
        else if (collisionResult.direction == CollisionDirection::RIGHT)
            m_pdata->spatialData.refPosX =
                etl::min(m_pdata->spatialData.refPosX + backStep, 128 - m_pdata->spatialData.sizeX);
        else if (collisionResult.direction == CollisionDirection::UP)
            m_pdata->spatialData.refPosY = etl::max(m_pdata->spatialData.refPosY - backStep, 0);
        else if (collisionResult.direction == CollisionDirection::DOWN)
            m_pdata->spatialData.refPosY =
                etl::min(m_pdata->spatialData.refPosY + backStep, 64 - m_pdata->spatialData.sizeY);
    } else {
        m_pdata->spatialData.consecutiveCollisionCount = 0;
    }
    //射击冷却处理
    if (m_pdata->attackData.shootCooldownTimer > 0) {
        uint8_t shootCooldownSpeed = m_pdata->attackData.shootCooldownSpeed;
        if (controlDelayTime * shootCooldownSpeed >= m_pdata->attackData.shootCooldownTimer)
            m_pdata->attackData.shootCooldownTimer = 0;
        else
            m_pdata->attackData.shootCooldownTimer -= controlDelayTime * shootCooldownSpeed;
    }
    //热量冷却处理
    if (m_pdata->heatData.currentHeat > 0) {
        m_pdata->heatData.heatCoolDownTimer += controlDelayTime;
        if (m_pdata->heatData.heatCoolDownTimer >= 200) //每200ms降温一次
        {
            if (m_pdata->heatData.currentHeat <= m_pdata->heatData.heatCoolDownRate)
                m_pdata->heatData.currentHeat = 0;
            else
                m_pdata->heatData.currentHeat -= m_pdata->heatData.heatCoolDownRate;
            m_pdata->heatData.heatCoolDownTimer = 0;
        }
    }
    //回血处理
    if (m_pdata->healthData.currentHealth < m_pdata->healthData.maxHealth) {
        m_pdata->healthData.healTimeCounter += controlDelayTime * m_pdata->healthData.healSpeed;
        if (m_pdata->healthData.healTimeCounter >= m_pdata->healthData.healResetTime) {
            if (m_pdata->healthData.currentHealth + m_pdata->healthData.healValue >= m_pdata->healthData.maxHealth)
                m_pdata->healthData.currentHealth = m_pdata->healthData.maxHealth;
            else
                m_pdata->healthData.currentHealth += m_pdata->healthData.healValue;
            m_pdata->healthData.healTimeCounter = 0;
        }
    }
    //检查血量状态
    if (m_pdata->healthData.currentHealth == 0 && !m_pdata->deathData.isDead) {
        m_pdata->deathData.isDead = true;
    }
}
```

其余代码就不展示了，基本就是复制，只需根据需求对虚接口进行重写即可

#### 管理器层
**该层级的设计主要是针对整个游戏运行的职责进行划分解耦**，`GameEntityManager`,`GameProgressManager`,`GamePerkCardManager`三者协作的关键在于清晰的职责边界与状态门控：进度与选卡控制何时推进逻辑或暂停到过场/选卡，实体管理器提供确定性更新与资源回收，卡片管理器以数据驱动改变玩家的RoleData

`GameEntityManager`统一掌控角色与子弹的生命周期与时序，采用固定容量的嵌入式向量存储多态指针，所有增删与遍历在临界区内执行，按“行动→状态→清理→渲染”的分阶段流程驱动：行动阶段调用角色/子弹的思考与动作，状态阶段推进位置与AABB碰撞、伤害与范围伤害并对玩家执行升级检查，清理阶段删除失效实体并向玩家结算经验，渲染阶段输出图像。
```cpp
#ifndef GAMEENTITYMANAGER_HPP
#define GAMEENTITYMANAGER_HPP

#include "math.h"
#include "role.hpp"
#include "leadingRole.hpp"
#include "enemyRole.hpp"
#include "etl/vector.h"

#include "FreeRTOS.h"
#include "task.h"

// 管理游戏中的实体：角色和子弹
// 会被多个模块引用
// 归gameProgressManager管理
class GameEntityManager {
public:
    etl::vector<IRole *, 20>    m_roles;   //角色池，存放所有角色指针
    etl::vector<IBullet *, 100> m_bullets; //子弹池，存放所有子弹指针
    bool                       isGameOver = false;
public:
    GameEntityManager() = default;
    ~GameEntityManager() {
        cleanUpAllRoles(true);
        cleanUpAllBullets(true);
    }
    GameEntityManager(const GameEntityManager &)            = delete;
    GameEntityManager &operator=(const GameEntityManager &) = delete;
public:

    //Add添加/********************************************************************/
    bool addRole(IRole *role) {
        if (role == nullptr || m_roles.full()) return false;
        taskENTER_CRITICAL();
        m_roles.push_back(role);
        taskEXIT_CRITICAL();
        return true;
    }

    bool addBullet(IBullet *bullet) {
        if (bullet == nullptr || m_bullets.full()) return false;
        taskENTER_CRITICAL();
        m_bullets.push_back(bullet);
        taskEXIT_CRITICAL();
        return true;
    }
/********************************************************************/
    //remove删除并销毁
 /********************************************************************/
    bool removeAndDestroyRole(IRole *role) {
        if (role == nullptr) return false;
        taskENTER_CRITICAL();
        auto it = etl::find(m_roles.begin(), m_roles.end(), role);
        if (it != m_roles.end()) {
            m_roles.erase(it);
            delete role;
            taskEXIT_CRITICAL();
            return true;
        }
        taskEXIT_CRITICAL();
        return false;
    }

    bool removeAndDestroyBullet(IBullet *bullet) {
        if (bullet == nullptr) return false;
        taskENTER_CRITICAL();
        auto it = etl::find(m_bullets.begin(), m_bullets.end(), bullet);
        if (it != m_bullets.end()) {
            m_bullets.erase(it);
            delete bullet;
            taskEXIT_CRITICAL();
            return true;
        }
        taskEXIT_CRITICAL();
        return false;
    }
    /********************************************************************/
    //获取player角色指针
 /********************************************************************/

    IRole *getPlayerRole() {
        taskENTER_CRITICAL();
        for (auto role : m_roles) {
            if (role != nullptr && role->getData()->identity == RoleIdentity::Player) {
                taskEXIT_CRITICAL();
                return role;
            }
        }
        taskEXIT_CRITICAL();
        return nullptr;
    }
   /********************************************************************/
    //清除需要回收的角色和子弹
 /********************************************************************/
    void cleanupInvalidRoles() {
       //...
    }

    void cleanupInvalidBullets() {
       //...
    }
  /********************************************************************/

    //碰撞检测
/********************************************************************/
    CollisionResult checkRoleRefPositionCollision(IRole *role_A) {
        //...
        return collisionDetected;
    }

    bool checkBulletRefPositionCollision(IBullet *bullet_A) {	        //...
        return collisionDetected;
    }
    /********************************************************************/
    //子弹范围伤害检测
/********************************************************************/
    void checkBulletRangeDamage(IBullet *bullet_A) {
        //....
    }
 /********************************************************************/
    //更新所有实体位置和状态
  /********************************************************************/

    /**
     * @brief 更新所有角色状态和位置
     */
    void updateAllRolesState() {
        taskENTER_CRITICAL();
        for (auto rolePtr : m_roles) {
            if (rolePtr != nullptr) {
                CollisionResult collisionResult = {false, CollisionDirection::NONE};
                if (rolePtr->getData()->initData.isInited) {
                    //碰撞处理
                    collisionResult = checkRoleRefPositionCollision(rolePtr);
                }
                rolePtr->update(collisionResult);
                if(rolePtr->getData()->identity == RoleIdentity::Player) {
                    LeadingRole* playerRole = (LeadingRole*)rolePtr;
                    playerRole->levelUp(); //检查升级
                }
            }
        }
        taskEXIT_CRITICAL();
    }

    /**
     * @brief 更新所有子弹状态和位置
     */
    void updateAllBulletsState() {
        taskENTER_CRITICAL();
        for (auto bulletPtr : m_bullets) {
            if (bulletPtr != nullptr) {
                CollisionResult collisionResult = {false, CollisionDirection::NONE};
                //碰撞处理
                bool isCollision = checkBulletRefPositionCollision(bulletPtr);
                if (isCollision) {
                    collisionResult.isCollision = true;
                    checkBulletRangeDamage(bulletPtr);
                }
                bulletPtr->update(collisionResult);
            }
        }
        taskEXIT_CRITICAL();
    }
  /********************************************************************/

    // 更新所有角色的AI行动决策
    /********************************************************************/
    void updateAllRolesActions() {
        taskENTER_CRITICAL();
        for (auto rolePtr : m_roles) {
            if (rolePtr != nullptr && rolePtr->getData()->initData.isInited) {
                rolePtr->think();
                rolePtr->doAction();
            }
        }
        taskEXIT_CRITICAL();
    }

    void updateAllBulletsActions() {
        taskENTER_CRITICAL();
        for (auto bulletPtr : m_bullets) {
            if (bulletPtr != nullptr) {
                bulletPtr->doAction();
            }
        }
        taskEXIT_CRITICAL();
    }
    /********************************************************************/
    // 绘制所有实体
   /********************************************************************/
    void drawAllRoles() {
        taskENTER_CRITICAL();
        for (auto rolePtr : m_roles) {
            if (rolePtr != nullptr && rolePtr->getData() != nullptr && rolePtr->getData()->img != nullptr) {
                rolePtr->drawRole();
            }
        }
        taskEXIT_CRITICAL();
    }

    void drawAllBullets() {
        taskENTER_CRITICAL();
        for (auto bulletPtr : m_bullets) {
            if (bulletPtr != nullptr && bulletPtr->m_data != nullptr && bulletPtr->m_data->img != nullptr) {
                bulletPtr->drawBullet();
            }
        }
        taskEXIT_CRITICAL();
    }
    /********************************************************************/

    //清除所有实体，资源回收
    void clearAllEntities(bool deleteObjects = true) {
        cleanUpAllRoles(deleteObjects);
        cleanUpAllBullets(deleteObjects);
    }
private:
    //清除所有角色和子弹，资源回收
    /********************************************************************/
    void cleanUpAllRoles(bool deleteObjects = true) {
        if (!deleteObjects) return;
        for (auto rolePtr : m_roles) {
            if (rolePtr != nullptr) delete rolePtr;
        }
        m_roles.clear();
    }

    void cleanUpAllBullets(bool deleteObjects = true) {
        if (!deleteObjects) return;
        for (auto bulletPtr : m_bullets) {
            if (bulletPtr != nullptr) delete bulletPtr;
        }
        m_bullets.clear();
    }
    /********************************************************************/
    //玩家角色获取经验值
  /********************************************************************/
    void gainDropExperiencePoints(uint16_t points) {
        LeadingRole* playerRole = (LeadingRole*)getPlayerRole();
        if (playerRole != nullptr && playerRole->getData()->level < 10) {
            playerRole->experiencePoints += points;
        }
    }
    /********************************************************************/
};

#endif // GAMEENTITYMANAGER_HPP
```

`GameProgressManager`负责关卡与波次推进以及Boss触发和过场展示：当清场（场上仅剩玩家）时递进波次/关卡，在关键节点触发选卡并按章节规则生成阵型或Boss，从而把战斗节奏和演出串联起来。
```cpp
#ifndef GAMEPROGRESSMANAGER_HPP
#define GAMEPROGRESSMANAGER_HPP
#include "gamePerkCardManager.hpp"
extern uint8_t             controlDelayTime; // 由 threads.cpp 定义
extern GameEntityManager   g_entityManager;
extern GamePerkCardManager g_perkCardManager;
enum class WaveType {
    //魑魅阵型
    CHIMEI_LINE = 0, // 10 魑魅直线阵
    CHIMEI_TRIANGLE, // 10 魑魅三角阵
    //飞廉阵型
    THREE_Feilian,   // 三飞廉
    FEILIAN_CLUSTER, // 飞廉群
    //古雕阵型
    GUDIAO_SINGLE,
    GUODIAO_DOUBLE,
    GUDIAO_SQUARE,
    //混合阵型
    MIXED_SMALL,  // 混合小型阵型 2feilian + 1Gudiao
    MIXED_MEDIUM, // 混合中型阵型 5feilian +1Gudiao
    MIXED_LARGE,  // 混合大型阵型 5feilian + 2Gudiao
};

enum class BOSS_TYPE {
    NONE = 0,
    TAO_TIE,   // 饕餮
    XIANG_LIU, // 相柳
    TAO_WU,    // 梼杌
};

class GameProgressManager {
public:
    uint8_t currentChapter = 1; // 当前游戏关卡
    uint8_t lastChapter    = 4; // 最大游戏关卡
    uint8_t currentWave            = 1;  // 当前波次
    uint8_t maxWave                = 15; // 最大波次
    uint8_t currentChapterMaxWaves = 0;  // 当前关卡总波次
    uint8_t time_count = 0;
    bool     isPlayingOpeningCG = false; // 是否播放开场动画
    uint16_t openingCGTimer     = 0;     // 开场动画计时器
    bool     isPlayingClearCG = false; // 是否播放通关动画
    uint16_t clearCGTimer     = 0;     // 通关动画计时器
    bool chatpter4Warning = false; // 第四章警告标记
    BOSS_TYPE showWhichBoss = BOSS_TYPE::NONE; // 展示Boss类型
    bool      showBoss      = false;           // 是否 展示Boss海报
    uint16_t  showBossTimer = 0;               // 展示Boss海报计时器
    //播放3秒Boss海报
    bool PauseGame = false; // 暂停游戏标记
public:
    GameProgressManager()  = default;
    ~GameProgressManager() = default;
    GameProgressManager(const GameProgressManager &)            = delete;
    GameProgressManager &operator=(const GameProgressManager &) = delete;
public:
    // 重置游戏进度
    void resetGameProgress() {
        // 重置实体管理器
        //...
    }

    // 更新游戏进度

    void updateGameProgress() {
     //...
    }

    void AddWaveEnemies() {
    //...
    }

    // 绘图展示功能
    // 绘制开场动画
    void drawOpeningCG() {
        if (openingCGTimer >= 2 * controlDelayTime)
            openingCGTimer -= 2 * controlDelayTime;
        else
            isPlayingOpeningCG = false;
        // 绘制动态圆圈效果
        OLED_DrawCircle(64, 32, 30 - (openingCGTimer / 100)+10, OLED_COLOR_NORMAL);
        OLED_DrawCircle(64, 32, 20 - (openingCGTimer / 150)+30 , OLED_COLOR_NORMAL);
        OLED_PrintString(30, 28, "CHIP TANKS", &font8x6, OLED_COLOR_NORMAL);
    }

    void drawClearCG() {
        if (clearCGTimer >= 2 * controlDelayTime)
            clearCGTimer -= 2 * controlDelayTime;
        else {
            isPlayingClearCG           = false;
            g_entityManager.isGameOver = true; // 游戏结束
        }
        // 致谢
        OLED_PrintString(1, 28, "THANK YOU FOR", &font8x6, OLED_COLOR_NORMAL);
        OLED_PrintString(1, 40, "PLAYING MY GAME", &font8x6, OLED_COLOR_NORMAL);
    }

    // 绘制展示Boss海报
    void drawShowBoss() {
        //...
    }
};

#endif // GAMEPROGRESSMANAGER_HPP
```

`GamePerkCardManager`管理Roguelike式成长：基于配置初始化卡片仓库，按需抽取待选卡、应用所选增益到玩家并回库未选卡，同时提供选卡界面渲染与交互状态。
```cpp
#ifndef GAMEPERKCARDMANAGER_HPP
#define GAMEPERKCARDMANAGER_HPP
#include "etl/vector.h"

#include "oled.h"
#include "prekCard.hpp"
#include "gameEntityManager.hpp"
#include "leadingRole.hpp"

// 管理游戏中的Perk卡片系统
// 引用GameEntityManager实例
// 归gameProgressManager管理
extern GameEntityManager g_entityManager;

class GamePerkCardManager {
public:
    GamePerkCardManager()  = default;
    ~GamePerkCardManager() = default;
    GamePerkCardManager(const GamePerkCardManager &)            = delete;
    GamePerkCardManager &operator=(const GamePerkCardManager &) = delete;

private:
    static const uint8_t MAX_CARD_COUNT       = 22; // 总卡片数（2*10 +1*2=22）
    static const uint8_t SELECTION_SLOT_COUNT = 3;  // 选卡槽数量（3张）
    etl::vector<PerkCard, MAX_CARD_COUNT>       m_cardWarehouse;  // 卡片仓库（存所有卡片）
    etl::vector<PerkCard, SELECTION_SLOT_COUNT> m_selectionSlots; // 选卡槽（临时存3张待选）

public:
    bool    isInited        = false; // 是否已初始化
    bool    m_isSelecting   = false; // 选卡状态（标记是否处于“选卡中”，避免重复触发）
    uint8_t m_selectedIndex = 0;     // 选中卡片索引（选卡槽内索引）
    uint8_t m_selectedSize  = 0;     // 选中卡片数量（选卡槽内数量）
public:
    // 初始化卡片仓库
    void initWarehouse() {
        m_cardWarehouse.clear();
        m_selectionSlots.clear();
        m_isSelecting = false;
        isInited      = true;
        // 遍历配置表，按数量创建卡片并加入仓库
        for (const auto &config : PERK_CARD_CONFIGS) {
            for (uint8_t i = 0; i < config.count; ++i) {
                PerkCard newCard(config.type, config.name, config.param);
                m_cardWarehouse.push_back(newCard);
            }
        }
    }

    bool triggerPerkSelection() {
        if (m_isSelecting || m_cardWarehouse.empty()) {
            return false; // 已在选卡中或无卡片可选，拒绝触发
        }
        m_selectionSlots.clear();
        // 可用卡片不足3张时，取全部（避免选卡槽为空）
        uint8_t selectCount = etl::min(SELECTION_SLOT_COUNT, (uint8_t)m_cardWarehouse.size());
        if (selectCount == 0) {
            return false; // 无可用卡片
        }
        m_selectedSize = selectCount;
        // 随机抽取selectCount张卡片，放入选卡槽（从仓库移除，避免重复抽）
        for (uint8_t i = 0; i < selectCount; ++i) {
            // 嵌入式随机算法：用系统滴答定时器做模运算（无需rand()）
            uint8_t randIdx      = rand() % m_cardWarehouse.size();
            uint8_t warehouseIdx = randIdx;
            // 从仓库移动到选卡槽（避免拷贝，提升效率）
           m_selectionSlots.push_back(m_cardWarehouse[warehouseIdx]);
            m_cardWarehouse.erase(m_cardWarehouse.begin() + warehouseIdx);
        }
        // 标记为选卡中，UI提示
        m_isSelecting = true;
        return true;
    }

    bool selectCard(uint8_t slotIndex) {
        // 前置校验：1. 在选卡中；2. 槽索引有效
        if (!m_isSelecting || slotIndex >= m_selectionSlots.size()) {
            return false;
        }
        // 处理选中卡片（slotIndex）
        PerkCard     selectedCard = m_selectionSlots[slotIndex];
        LeadingRole *player       = (LeadingRole *)g_entityManager.getPlayerRole();
        if (player == nullptr) {
            return false; // 未找到玩家角色，无法应用卡片效果
        }
        // 应用卡片效果
        switch (selectedCard.type) {
        case PerkCardType::HEAL_SPEED_UP:
            player->getData()->healthData.healSpeed += selectedCard.param;
            break;
        case PerkCardType::HEAL_AMOUNT_UP:
            player->getData()->healthData.healValue += selectedCard.param;
            break;
        case PerkCardType::HEALTH_UP:
            player->getData()->healthData.maxHealth += selectedCard.param;
            player->getData()->healthData.currentHealth = player->getData()->healthData.maxHealth;
            break;
        case PerkCardType::ATTACK_UP:
            player->getData()->attackData.attackPower += selectedCard.param;
            break;
        case PerkCardType::ATTACK_SPEED_UP:
            player->getData()->attackData.shootCooldownSpeed += selectedCard.param;
            break;
        case PerkCardType::HEAT_CAPACITY_UP:
            player->getData()->heatData.maxHeat += selectedCard.param;
            break;
        case PerkCardType::HEAT_COOL_DOWN_UP:
            player->getData()->heatData.heatCoolDownRate += selectedCard.param;
            break;
        case PerkCardType::UNLOCK_FIREBALL:
            player->bulletTypeOwned.fireBallBulletOwed = 1;
            break;
        case PerkCardType::UNLOCK_LIGHTNING:
            player->bulletTypeOwned.lightningLineBulletOwed = 1;
            break;
        case PerkCardType::FIREBALL_RANGE_UP:
            player->getData()->attackData.bulletRange += selectedCard.param;
            break;
        case PerkCardType::LIGHTNING_MULTIPLIER_UP:
            player->getData()->attackData.bulletDamageMultiplier += (static_cast<float>(selectedCard.param) / 10.0f);
            break;
        case PerkCardType::MOVE_SPEED_UP:
            player->getData()->spatialData.moveSpeed += selectedCard.param;
            break;
        default:
            break;
        }
        // 移除选中卡片，清理未选中卡片，重置选卡状态
        m_selectionSlots.erase(m_selectionSlots.begin() + slotIndex);
        returnUnselectedCards();
        m_isSelecting = false;
        return true;
    }

    // 辅助接口：未选中的卡片回库
    void returnUnselectedCards() {
        for (uint8_t i = 0; i < m_selectionSlots.size(); ++i) {
            // 跳过选中的卡片（slotIndex已处理）
            m_cardWarehouse.push_back(m_selectionSlots[i]);
        }
        m_selectionSlots.clear();
    }

    void drawSelectionUI() {
        if (!m_isSelecting) {
            return; // 非选卡状态，无需绘制
        }
        // 绘制选卡槽UI（简化示例，实际根据UI框架实现）
        for (uint8_t i = 0; i < m_selectionSlots.size(); ++i) {
            OLED_PrintString(10, 10 + (i * 20), m_selectionSlots[i].name, &font8x6, OLED_COLOR_NORMAL);
        }
        OLED_DrawCircle(5, 12 + (m_selectedIndex * 20), 2, OLED_COLOR_NORMAL); // 绘制选中指示器
    }
};

#endif // GAMEPERKCARDMANAGER_HPP
```
#### 应用逻辑层
按“主循环驱动、输入分发、渲染输出”三类职责拆分成独立的 FreeRTOS 任务，全局状态作为门控，保证在过场、选卡、战斗三种模式之间平滑切换。

核心数据与行为推进集中在 `gameControlThread`，输入解析与状态写入在 `keyScanThread`，画面组合与输出在 `oledTaskThread`。

给出伪代码如下：
```cpp
oledTaskThread:
初始化: delay(30) → OLED_Init()
每帧:
OLED_NewFrame()
若 !g_entityManager.isGameOver:
若 g_progressManager.isPlayingOpeningCG: drawOpeningCG()
否则若 g_progressManager.isPlayingClearCG: drawClearCG()
否则若 g_progressManager.showBoss: drawShowBoss()
否则若 g_perkCardManager.m_isSelecting && g_perkCardManager.isInited: drawSelectionUI()
否则（战斗界面）:
若玩家存在: drawPlayerHUD(HP, LV)
g_entityManager.drawAllRoles()；g_entityManager.drawAllBullets()
OLED_ShowFrame()
delay(controlDelayTime * 2)

keyScanThread:
初始化: scanDelay=40 → key.init()
每轮:
key.scan()
若游戏进行中（非 GameOver/开场/Boss 展示/通关）:
若 !g_perkCardManager.m_isSelecting（战斗输入态）:
scanDelay=40
pLeadingRole = (LeadingRole*) g_entityManager.getPlayerRole()
若玩家存在: 按键映射到动作态与方向（LEFT/DOWN/UP/RIGHT → ActionState::MOVING + MoveMode）
否则（选卡输入态）:
scanDelay=100
光标索引在 [0, m_selectedSize-1] 间夹紧
keyDown → 索引+1（上限保护）；keyUp → 索引-1（下限保护）
keyConfirm → g_perkCardManager.selectCard(m_selectedIndex)
delay(scanDelay)

gameControlThread:
启动: g_entityManager.isGameOver = true（强制初始重置）
每轮:
若 g_entityManager.isGameOver: g_progressManager.resetGameProgress()（清空实体→添加玩家→初始化卡池→开场动画计时）
否则若逻辑可推进（非开场/非Boss展示/非通关/非选卡）:
进度推进: g_progressManager.updateGameProgress()（清场判定→波次/关卡递进→半程/过关触发选卡→AddWaveEnemies()）
行为阶段: g_entityManager.updateAllRolesActions()；g_entityManager.updateAllBulletsActions()
状态阶段:
g_entityManager.updateAllRolesState()（AABB碰撞→方向判定→位移/回退→冷却/热量/回血→玩家 levelUp()）
g_entityManager.updateAllBulletsState()（命中检测→范围伤害→位移/寿命）
清理阶段: cleanupInvalidRoles()（敌人死亡发经验、玩家死亡置 GameOver）；cleanupInvalidBullets()
delay(controlDelayTime)

```

#### timer定时器的设计
代码比较重点一个设计在于timer计时器，每一帧增加或减少帧间隔的时间（相当于决定多少帧触发某一个动作，可以用此来作为一个门控）

- shootCooldownTimer：射击冷却倒计时，归零前禁止再次开火。
- heatCoolDownTimer：热量冷却触发间隔计时，累计到阈值（200ms）降低一次热量。
- healTimeCounter：被动回血累积时间，达到阈值（healResetTime）回复 healValue。
- deathTimer：死亡后保留与动画展示时间窗，便于延迟清理。
- consecutiveCollisionCount（计数型“时间替代”）：连续帧碰撞累计，扩大回退步幅直至解除。
- action_timer（敌人/技能内部使用）：驱动攻击模式阶段切换与技能节拍。
- openingCGTimer / clearCGTimer / showBossTimer（过场类）：控制开场、通关、Boss 展示持续时间。
- shootCooldownResetTime / healResetTime 等“阈值型常量”：定义倒计时起点或触发周期长度。

**核心：所有计时器是“离散步长 + 阈值触发”模型**
增加每一帧的`controlDelayTime`，用统一帧步长驱动一组简单的线性计时器，以门槛触发和双重约束塑造节奏与资源循环

**核心作用**：**解耦时间进程和行为**，计时器只管理时间进程，不直接耦合行为；行为在触发点读取状态执行。

## Bug 记录与解决方案

### 1. 热量系统临界区死锁

**问题现象**：当玩家热量达到上限后，游戏完全冻结，所有角色停止更新，画面不再刷新。

**问题分析**：
在 `LeadingRole::shoot()` 函数中，代码在函数开头调用了 `taskENTER_CRITICAL()` 进入 FreeRTOS 临界区，但在热量检查失败的早期 `return` 语句中**没有调用 `taskEXIT_CRITICAL()` 就直接返回**。

```cpp
// 问题代码
void LeadingRole::shoot(uint8_t x, uint8_t y, BulletType type) {
    taskENTER_CRITICAL();  // 进入临界区
    
    if(m_pdata->heatData.currentHeat + ... > m_pdata->heatData.maxHeat)
        return; // BUG! 没有退出临界区就返回  调度器永久锁死
    ...
}
```

当热量超限时，函数直接返回，导致调度器被永久禁用，所有 FreeRTOS 任务都无法运行。

**解决方案**：
为所有早期返回点添加 `taskEXIT_CRITICAL()` 调用：

```cpp
// 修复后
if(m_pdata->heatData.currentHeat + ... > m_pdata->heatData.maxHeat) {
    taskEXIT_CRITICAL();  // 先退出临界区
    return;
}
```

---

### 2. 热量冷却无符号下溢

**问题现象**：玩家热量值会莫名其妙突然变得非常大（如从10点突然变成240多点）。

**问题分析**：
在 `IRole::update()` 的热量冷却逻辑中，条件检查与实际减少量不匹配：

```cpp
// 问题代码
if (m_pdata->heatData.currentHeat <= m_pdata->heatData.heatCoolDownRate)  // 检查 4
    m_pdata->heatData.currentHeat = 0;
else
    m_pdata->heatData.currentHeat -= m_pdata->heatData.heatCoolDownRate * 5; // 减 20
```

当 `currentHeat` 在 5~19 之间时：
- 条件 `<= 4` 不满足，进入 else 分支
- 执行 `currentHeat -= 20`，由于 `currentHeat` 是 `uint8_t`（无符号），发生下溢
- 例如：`10 - 20 = -10`  无符号表示为 `246`

**解决方案**：
统一条件检查与减少量：

```cpp
// 修复后
uint8_t coolAmount = m_pdata->heatData.heatCoolDownRate * 5;
if (m_pdata->heatData.currentHeat <= coolAmount)
    m_pdata->heatData.currentHeat = 0;
else
    m_pdata->heatData.currentHeat -= coolAmount;
```

---

### 3. 快速上下电导致OLED显示翻转

**问题现象**：使用独立电源快速上下电时，OLED 屏幕显示内容发生翻转，有时是180度全屏翻转，有时是部分内容翻转。

**问题分析**：

根据 SSD1306 数据手册，显示方向由两个关键命令控制：
- `0xA0`/`0xA1`：段重映射（Segment Re-map），控制水平方向
- `0xC0`/`0xC8`：COM 输出扫描方向，控制垂直方向

快速上下电时出现翻转的原因：

1. **SSD1306 内部状态不确定**：快速上下电时，SSD1306 的内部寄存器可能没有完全复位到默认值，保留了上次的配置状态
2. **初始化等待时间不足**：原代码只等待 30ms，不足以让电源和 SSD1306 内部电路稳定
3. **I2C 通信可能失败**：上电瞬间 I2C 总线可能不稳定，部分初始化命令丢失
4. **方向配置命令未重复确认**：若单次发送方向命令时恰好传输失败，就会导致显示翻转

**解决方案**：

**1. 增强 `OLED_Init()` 初始化序列**：

```c
void OLED_Init()
{
  // 阶段1: 确保SSD1306完全就绪
  osDelay(100);  // 等待电源稳定和内部复位完成
  
  OLED_SendCmd(0xAE); // 关闭显示
  
  // ... 其他配置 ...
  
  // 阶段4: 显示方向配置（关键！防止翻转）
  // 先发送默认方向命令，再发送目标方向命令，确保状态确定
  OLED_SendCmd(0xA0); // 段重映射：先设为默认
  OLED_SendCmd(0xA1); // 段重映射：再设为翻转
  
  OLED_SendCmd(0xC0); // COM扫描方向：先设为默认
  OLED_SendCmd(0xC8); // COM扫描方向：再设为翻转
  
  // ... 其他配置 ...
  
  osDelay(10);      // 等待电荷泵稳定
  OLED_SendCmd(0xAF); // 开启显示
}
```

**2. 调整线程初始化延时**：

```cpp
void oledTaskThread(void *argument) {
    osDelay(50); // 增加等待时间（加上OLED_Init内部的100ms，共约150ms）
    OLED_Init();
    // ...
}
```

**改进要点总结**：

| 改进项 | 说明 |
|---|---|
| 增加初始化前延时 | 等待 100ms 让电源和 SSD1306 内部复位完成 |
| 双重方向配置 | 先发默认方向命令，再发目标方向命令，确保状态确定 |
| 规范化命令顺序 | 按 SSD1306 手册推荐顺序重新组织初始化命令 |
| 增加电荷泵稳定延时 | 开启显示前等待 10ms |

**硬件层面补充措施**（若软件修复后问题仍存在）：
1. 在 OLED 模块的 RES 引脚接 GPIO，初始化时先拉低 10ms 再拉高进行硬复位
2. 在 OLED 电源入口增加 100μF 电解电容 + 100nF 陶瓷电容进行滤波
3. 确保 I2C 的 SDA/SCL 有合适的上拉电阻（通常 4.7kΩ）

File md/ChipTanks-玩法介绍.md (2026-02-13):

## 🎮 游戏介绍：Chip Tanks (芯片坦克)

**Chip Tanks**  是一款运行在 STM32 嵌入式平台上的  **Roguelike 俯视视角弹幕射击游戏**。玩家将操控一辆微型坦克，在 OLED 屏幕呈现的战场上，迎战源自《山海经》与中国上古神话的机械化凶兽。

通过击败敌人获取经验，升级并抽取强力的  **PerkCard（天赋卡）**，构建属于你的战斗流派，挑战强大的关卡 BOSS！

## 🕹️ 游戏类型与核心机制

- **类型**：Roguelike / 弹幕射击 (STG) / 嵌入式游戏
- **核心循环**：战斗 -> 积累经验 -> 升级 -> **三选一抽卡 (Perk)** -> 挑战 BOSS -> 进入下一章。
- **热量系统 (Heat System)**：
  - 坦克的射击受到“热量”限制。
  - 普通子弹、火球、闪电链会产生不同程度的热量。
  - 当热量达到上限时，坦克将**过热无法射击**，必须等待冷却。
  - 策略点：玩家需要在输出火力和控制热量之间寻找平衡。
- **自动回血**：坦克具备自我修复功能，在不受伤害一段时间后会缓慢恢复生命值。

## 🎮 操作指南

游戏通过按键进行操作：

- **移动控制**：
  - **KeyLeft_up**：向上移动 (UP) / 菜单上选
  - **KeyLeft_down**：向下移动 (DOWN) / 菜单下选
  - **KeyLeft_left**：向左移动 (LEFT)
  - **KeyLeft_right**：向右移动 (RIGHT)
- **功能控制**：
  - **KeyRight_all**：确认选择 (Select) —— 用于在升级界面选择 PerkCard。
- **攻击**：
  - 坦克会自动锁定并攻击，自动判定冷却和热量。

## 🃏 PerkCard (天赋卡) 系统详解

PerkCard 是游戏的核心 Roguelike 元素。每当玩家升级（特定等级）时，系统会随机提供 3 张卡片供玩家选择。

以下是所有卡片的效果说明：

### 🛡️ 生存与恢复类

1. **HEAL_SPEED_UP (回复速度提升)**
   - **效果**：加快自动回血的频率。让你在受损后能更快开始修复。
2. **HEAL_AMOUNT_UP (回复量提升)**
   - **效果**：增加每次回血恢复的生命值数值。
3. **HEALTH_UP (生命上限提升)**
   - **效果**：大幅提升坦克的最大生命值，并且**瞬间回满所有生命值**。救命神卡。

### ⚔️ 攻击与火力类

4. **ATTACK_UP (攻击力提升)**
   - **效果**：直接增加所有子弹的基础伤害。
5. **ATTACK_SPEED_UP (攻速提升)**
   - **效果**：减少射击的冷却时间，让你能更频繁地发射子弹（需配合热量卡使用，否则容易过热）。
6. **UNLOCK_FIREBALL (解锁：火球弹)**
   - **效果**：解锁副武器**火球**。火球击中敌人后会造成**范围爆炸伤害**（AOE），适合清理成群的小怪。
7. **UNLOCK_LIGHTNING (解锁：闪电链)**
   - **效果**：解锁副武器**闪电链**。闪电具有极高的单体伤害倍率，是击杀 BOSS 的利器。
8. **FIREBALL_RANGE_UP (火球范围提升)**
   - **效果**：扩大火球爆炸的伤害半径，增强 AOE 能力。
9. **LIGHTNING_MULTIPLIER_UP (闪电伤害倍率提升)**
   - **效果**：大幅提升闪电链的伤害倍数，使其成为终极杀伤武器。

### 🔥 热量管理类 (核心机制)

10. **HEAT_CAPACITY_UP (热容上限提升)**
    - **效果**：提升热量槽上限。允许你在过热前连续发射更多子弹。
11. **HEAT_COOL_DOWN_UP (散热速度提升)**
    - **效果**：加快热量的自然冷却速度。让你在停止射击后能更快恢复开火能力。

### 🚀 机动类

12. **MOVE_SPEED_UP (移速提升)**
    - **效果**：提升坦克的移动速度，更利于躲避密集的弹幕和敌人的冲撞。

## 👾 敌人图鉴 (山海经机械兽)

你将面对形态各异的敌人，它们拥有不同的攻击模式：

### 普通敌人

- **飞廉 (Feilian)**：小型敌人。移动速度极快，轨迹飘忽不定，通常成群结队出现进行骚扰。
- **蛊雕 (Gudiao)**：中型敌人。擅长远程伏击，从身体两侧发射高伤子弹，死亡时会发射一颗复仇火球。
- **魑魅 (ChiMei)**：极小敌人。只会进行自杀式冲撞，速度极快，一旦接触造成大量伤害。

### 精英敌人

- **驳 (Bo)**：马形神兽，白身黑尾，头生独角。会使用**冲锋践踏**直扑玩家，发射**扇形虎爪弹幕**，以及释放**鼓音震荡波**。
- **胜遇 (Shengyu)**：赤色野鸡状凶兽，擅长干扰。会在场地生成**遮挡视野的水雾**，推出**迷雾屏障**，并发射**连续雷鸣子弹**。
- **狸力 (Lili)**：猪形神兽，与土系能力绑定。会发射**土涌火球**，释放**獠吠扇形震波**，并在随机位置埋设**延时爆炸陷阱**。

### 关卡 BOSS

- **饕餮 (Taotie)**：贪婪巨兽，四凶之一。血量极厚，会使用**吞噬**技能将玩家吸向自己，或发起猛烈的**冲撞**和**碾压**。
- **梼杌 (Taowu)**：凶暴巨兽，四凶之一。擅长**闪现**移动，能释放覆盖全屏的**随机弹幕**和**诡雷**。
- **相柳 (Xiangliu)**：灾难巨兽。九头蛇身，能同时发射**九排弹幕**，释放闪电与火球，并能**召唤**大量小怪协同作战。
- **混沌 (Hundun)**：**四凶之首**，无面目的原始巨兽。血量最高，会**随机闪烁移动并发射八方向弹幕**，生成**七窍封印干扰视野**，使用**虚空牵引**将玩家拉向自身，释放**螺旋式混沌漩涡**和**时空裂隙弹幕墙**，以及终极技能**归于混沌**——全屏弹幕攻击（血量越低缺口越小）。
  ***

**最后，祝您在 Chip Tanks 的世界中武运昌隆**

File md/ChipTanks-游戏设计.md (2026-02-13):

## 设计思路简介

### 游戏类型设计

**嵌入式平台上的“山海经”题材 Rougelite 弹幕射击游戏**（STG）

**横版/竖版射击 (Shoot 'em up / STG)**：
游戏的核心玩法是控制主角在 OLED 屏幕上移动，发射子弹消灭源源不断的敌人。

**Roguelite (轻度肉鸽)**：
**随机成长**：包含  `PerkCard`  系统和  `gamePerkCardManager`。玩家升级后会触发 Perk 选择（如“攻速提升”、“解锁火球”、“解锁闪电”），每次游玩的构建（Build）都是不同的。
**永久死亡/单局进程**：通常此类嵌入式游戏为单局挑战模式。

**热量系统 (Overheat System)**：不同于传统的无限射击，游戏引入了“热量”机制（`heatData`）。普通子弹、火球、闪电消耗不同的热量，过热可能导致无法射击。这要求玩家在“爆发输出”和“控温”之间做决策，增加了战术深度。

### 游戏背景设计

基于中国古代神话典籍《山海经》。所有的敌人都是古代神话中的妖兽，所有敌人的设计元素均来自于《山海经》。

通过将古老的神话生物与“坦克/射击”、“OLED 显示”、“热量过载”等科技元素结合形成反差。

- **敌人**：
- **小怪**：飞廉（风神）、蛊雕（食人雕）、魑魅（山林鬼怪）
- **BOSS**：上古四凶（饕餮、梼杌）和凶神（相柳）

## 游戏具体设计

### 机制设计

所有角色遵循以下基础物理与战斗公式：

#### 1. 基础战斗机制

- **射击冷却 (Cooldown):** `射击间隔(ms) = resetTime / Speed`。
- **热量机制 (Heat):**
  - **冷却速率:**  基类 `IRole::update()` 每 **500ms** 结算一次，减少 `heatCoolDownRate * 5` 点热量（等效每秒 `heatCoolDownRate * 10`）。
  - **热量消耗倍率（与 `heatPerShot` 基值相乘）:**
    - 普通子弹: **1.0x**
    - 火球弹: **2.0x**
    - 闪电链: **2.0x** （当前实现）
- **伤害计算:**
  - **普通子弹:** `Damage = attackPower`
  - **火球弹:** `Damage = attackPower + 10` (直接伤害 + 范围伤害)（造成两次）
  - **闪电链:** `Damage = (multiplier * attackPower) + 30` (穿透伤害
- **恢复计算**：`恢复间隔(ms) = resetTime / Speed , 恢复量 = healValue`

子弹设计逻辑，火球弹是大范围清杂子弹，闪电链是高伤害穿透子弹

#### 2.升级机制 (Level-Up Mechanism)

升级是玩家成长的基础驱动力。

**经验获取 (XP Gain)**

- **来源**: 击杀敌人。
- **数值**: 每个敌人都有定义的  `dropExp`（掉落经验值）。
  - 例如  `FeilianEnemy`  构造函数中传入  `dropExp`
- **过程**: 当敌人死亡（[die()](vscode-file://vscode-app/c:/IncludeAll/Tools/VSCode/Microsoft%20VS%20Code/resources/app/out/vs/code/electron-browser/workbench/workbench.html)）时，其  `dropExp`  会被加到玩家（`LeadingRole`）的当前经验池中

**升级判定**

- **阈值**: 玩家拥有  `currentExp`  和  `maxExp`（升级所需经验）
- **逻辑**: 当  `currentExp >= maxExp`  时，触发升级
- **成长曲线**: 升级后，下一级所需的  `maxExp`  通常会增加（例如：`maxExp = maxExp * 1.2`  或固定增量），增加升级难度

**升级后的基础提升 (Base Stat Growth)**
每次升级，玩家角色会自动获得一些基础属性的提升，无需选择：

- **生命值上限 (Max Health)**: 提升生存能力（例如  `maxHealth += 10`）。
- **回满血**: 升级通常伴随着状态恢复
- **攻击力/热量上限**: 可能伴随微量的线性成长（取决于  `LeadingRole`  的具体实现）
  **触发特殊事件**
- **Perk 选择**: 每隔特定等级（**每 2 级**），触发一次 PerkCard 选择
- **形态变化**: ，会改变角色的基础攻速

#### 3.PerkCard 机制 (天赋卡片系统)

PerkCard 是游戏的**Roguelike**核心元素，允许玩家在单局游戏中构建不同的战斗流派。
**卡片定义**
卡片包含以下属性：

- **Type (类型)**: 枚举值，决定卡片的功能。
- **Name (名称)**: 显示在 OLED 屏幕上的文本（如 "Attack +5"）。
- **Param (参数)**: 数值强度（如加 5 点攻击，参数就是 5）。
- **卡片类型与效果详解**

| 卡片类型 | 效果描述 | 关联代码变量 |
| :--- | :--- | :--- |
| **HEAL_SPEED_UP** | 提升回血速度 | `healthData.healSpeed` |
| **HEAL_AMOUNT_UP** | 提升单次回复量 | `healthData.healValue` |
| **HEALTH_UP** | 提升生命上限 | `healthData.maxHealth` |
| **ATTACK_UP** | 提升基础攻击力 | `attackData.attackPower` |
| **ATTACK_SPEED_UP** | 提升射击频率 | `attackData.shootCooldownSpeed` |
| **HEAT_CAPACITY_UP** | 提升热量上限 | `heatData.maxHeat` |
| **HEAT_COOL_DOWN_UP** | 提升散热速度 | `heatData.heatCoolDownRate` |
| **UNLOCK_FIREBALL** | **解锁新武器** | 玩家解锁新的子弹 |
| **UNLOCK_LIGHTNING** | **解锁新武器** | 玩家解锁新的子弹 |
| **FIREBALL_RANGE_UP** | 提升火球爆炸范围 | `attackData.bulletRange` |
| **LIGHTNING_MULTIPLIER** | 提升闪电伤害倍率 | `attackData.bulletDamageMultiplier` |
| **MOVE_SPEED_UP** | 提升移动速度 | `spatialData.moveSpeed` |

##### 流派构建

通过升级和 Perk 的组合，玩家可以形成不同的策略：

1. **加特林流 (高攻速 + 高散热)**:
   - 重点选择  `ATTACK_SPEED_UP`  和  `HEAT_COOL_DOWN_UP`。
   - 结果：发射普通子弹像泼水一样，利用高频率触发伤害。
2. **重炮流 (火球 + 爆炸范围 + 高攻击)**:
   - 重点选择  `UNLOCK_FIREBALL`, `ATTACK_UP`, `FIREBALL_RANGE_UP`。
   - 结果：攻速慢，但一发火球能清空一片区域。
3. **雷神流 (闪电 + 倍率 + 高攻击 )**:
   - 重点选择  `UNLOCK_LIGHTNING`, `LIGHTNING_MULTIPLIER_UP`。
   - 结果：利用闪电的穿透特性和高倍率伤害，瞬间秒杀直线上的敌人。
4. **坦克流 (回血 + 高血量)**:
   - 重点选择  `HEALTH_UP`, `HEAL_SPEED_UP`。
   - 结果：依靠中的自动回血逻辑（`healTimeCounter`），硬抗敌人

### 敌人设计风格

#### 定位

**Fodder (炮灰/骚扰)**：飞廉（高机动低伤）、魑魅（自爆卡车），主要用于干扰走位和消耗玩家精力。

**Elite (精英/高威胁)**：驳、胜遇、狸力，拥有多种攻击模式，强迫玩家进行特定走位和策略应对。蛊雕拥有亡语机制（死后发火球）。

**Boss (首领)**：拥有多阶段或多技能循环。
_饕餮_：近战系 BOSS，强调位移控制（拉人、冲撞）。
_梼杌_：敏捷系 BOSS，强调反应速度（闪现、狂暴弹幕）。
_相柳_：法师/召唤系 BOSS，强调全屏躲避和处理小怪（AOE、召唤）。
_混沌_：四凶之首，混乱系 BOSS，强调视野干扰、随机弹幕和牵引玩家。

#### 攻击机制与数值

##### 1. 飞廉 (FeilianEnemy)

- **定位**：小型高速骚扰者
- **原型**：风神，鹿身翼角。
- **数值设定**：
  - **体型**：12x12 (小)
  - **移动**：高速，轨迹飘忽不定（模拟风的特性）。
  - **攻击力**：低。
  - **死亡动画**：250ms。
- **攻击方式**：
  - **普通射击**：只发射普通子弹。
- **战术意义**：单体威胁小，依靠数量和难以预测的移动轨迹干扰玩家，消耗玩家的注意力。

##### 2. 蛊雕 (GudiaoEnemy)

- **定位**：中型伏击者
- **原型**：食人猛禽，似雕有角，音如婴儿。
- **数值设定**：
  - **体型**：15x15 (中)
  - **移动**：中速，飞行轨迹较直接。
  - **攻击力**：较高。
  - **死亡动画**：250ms。
- **攻击方式**：
  - **双侧射击**：每次从身体中心的两侧发射普通子弹（高伤害）。
  - **亡语（Death Rattle）**：死亡后会发射一颗火球弹，对击杀者造成最后威胁。
- **战术意义**：需要优先处理的高伤害单位，且击杀时需注意躲避亡语子弹。

##### 3. 魑魅 (ChiMeiEnemy)

- **定位**：自杀式冲锋怪
- **原型**：山林鬼怪，迷惑人心。
- **数值设定**：
  - **体型**：8x8 (极小)
  - **移动**：高速。
  - **死亡动画**：250ms。
- **攻击方式**：
  - **自杀冲撞**：不发射子弹，通过高速移动直接撞击玩家造成伤害。
- **战术意义**：迫使玩家保持移动，不能停留在原地。

##### 4. 饕餮 (TaotieEnemy)

- **定位**：近战坦克型 BOSS
- **原型**：四凶之一，贪婪，吞噬万物。
- **数值设定**：
  - **体型**：64x64 (巨大)
  - **HP**：高血量。
  - **攻击力**：高。
  - **移动**：低速。
  - **死亡动画**：500ms。
- **攻击方式 (5 种模式)**：
  1. **吞噬 (Devour)**：将玩家向自己拉近 (`pullDistance = 30`)，然后进行攻击。
  2. **弹幕**：发射三排普通子弹。
  3. **冲撞 (Ram)**：向前冲锋 (`chargeDistance = 30`) 进行撞击。
  4. **碾压 (Crush)**：从玩家左侧出现 (`crushChargeDistance = 100`)，向后碾压，封锁走位。
  5. **组合技**：将玩家拉近，同时向前冲锋 (`pullAndChargeDistance = 50`)。

##### 5. 梼杌 (TaowuEnemy)

- **定位**：高机动弹幕型 BOSS
- **原型**：四凶之一，顽固凶暴。
- **数值设定**：
  - **体型**：64x64 (巨大)
  - **HP**：低血量（相对其他 BOSS）。
  - **攻击力**：高。
  - **移动**：高速，擅长闪现 (Blink)。
  - **死亡动画**：500ms。
- **攻击方式 (6 种模式)**：
  1. **狂暴弹幕**：闪现至中间，随机发射大量普通子弹。**狂暴机制**：血量越低，持续时间越长（3 秒 -> 6 秒），频率 5 发/秒。
  2. **随机火球**：随机位置发射 5 个火球弹。
  3. **混合射击**：中间发射 1 颗火球，两侧边缘各发射 2 颗普通子弹。
  4. **缺口阵型**：发射一排子弹，仅中间留有缺口（迫使玩家钻缝）。
  5. **诡雷闪现**：原地留下一颗火球弹，本体消失。
  6. **追击闪现**：消除冷却 CD，直接闪现对齐玩家位置。

##### 6. 相柳 (XiangliuEnemy)

- **定位**：召唤与全屏压制型 BOSS
- **原型**：九头蛇怪，所过之处尽成泽国。
- **数值设定**：
  - **体型**：64x64 (巨大)
  - **HP**：高血量。
  - **攻击力**：高。
  - **移动**：中速。
  - **死亡动画**：500ms。
- **攻击方式 (6 种模式)**：
  1. **九头齐射**：发射  **9 排**  普通子弹（覆盖面极大）。
  2. **雷狱**：发射  **3 排**  闪电链（穿透伤害）。
  3. **火海**：发射  **3 排**  火球弹（范围爆炸）。
  4. **召唤魑魅**：生成 3 只自爆怪 (ChiMei) 协同作战。
  5. **召唤飞廉**：生成 2 只高速怪 (Feilian) 协同作战。
  6. **召唤蛊雕**：生成 1 只高伤怪 (Gudiao) 协同作战。
##### 7. 混沌 (HundunEnemy) - 四凶之首

- **定位**：混乱与干扰型 BOSS（四凶之首）
- **原型**：《山海经》记载其形如黄囊，赤如丹火，六足四翼，无面目；《庄子》有"七窍凿而混沌死"典故。
- **数值设定**：
  - **体型**：64x64 (巨大)
  - **HP**：最高血量（400 + Level×1200）。
  - **攻击力**：中高（8 + Level×6）。
  - **移动**：低速但可瞬移。
  - **死亡动画**：500ms。
- **攻击方式 (6 种模式)**：
  1. **混沌涌动**：随机闪烁移动，同时向 8 个方向发射普通子弹，低血量时夹杂火球。持续 3000ms，每 500ms 闪烁一次。
  2. **七窍封印**：在屏幕上生成 7 个闪烁干扰区域遮挡视野，持续 2000ms（呼应"七窍凿而混沌死"典故）。
  3. **虚空牵引**：将玩家向混沌位置缓慢拉近，同时发射追踪火球。持续 2500ms，每 300ms 拉近一次。
  4. **混沌漩涡**：螺旋式发射子弹，Y位置按正弦波扫射。持续 2000ms，每 150ms 发射一发。
  5. **时空裂隙**：快速发射带随机缺口的弹幕墙，缺口位置每轮变化。持续 2500ms，每 550ms 发射一轮。
  6. **归于混沌**：全屏弹幕攻击，中间有安全缺口，血量越低缺口越小。警告 500ms 后发射。

##### 8. 驳 (BoEnemy)

- **定位**：精英级中型敌人
- **原型**：《山海经·西山经》记载，马形神兽，白身黑尾，头生独角，有虎牙虎爪，叫声如鼓，能捕食虎豹。
- **数值设定**：
  - **体型**：24x24 (中)
  - **HP**：40 + Level×200
  - **攻击力**：6 + Level×2
  - **移动**：中速（2）。
  - **死亡动画**：300ms。
- **攻击方式 (3 种模式)**：
  1. **冲锋践踏**：向玩家方向快速直线冲锋，造成碰撞伤害。冲锋距离 40 像素，持续 800ms。
  2. **虎牙利爪**：发射 3 发呈扇形的普通子弹（呼应"虎牙爪"）。持续 200ms。
  3. **鼓音震荡**：发射一排横向冲击波子弹（呼应"音如鼓音"）。持续 300ms。

##### 9. 胜遇 (ShengyuEnemy)

- **定位**：精英级干扰型敌人
- **原型**：《山海经·西次三经》记载，赤色野鸡状凶兽，叫声独特，出现预示洪水灾厄。
- **数值设定**：
  - **体型**：20x20 (中)
  - **HP**：50 + Level×220
  - **攻击力**：10 + Level×4
  - **移动**：中速（2）。
  - **死亡动画**：300ms。
- **攻击方式 (3 种模式)**：
  1. **水雾弥漫**：在场景中生成 2 个迷雾区域遮挡玩家视线（呼应"大水"典故）。持续 3000ms。
  2. **洪波推涌**：往前推出一长条迷雾屏障，长度 110 像素，逐渐消散。持续 2800ms。
  3. **赤羽雷鸣**：发射一串 5 发普通子弹（呼应"赤"色特征）。每 150ms 发射一发，持续 800ms。

##### 10. 狸力 (LiliEnemy)

- **定位**：精英级土系敌人
- **原型**：《山海经·南山经》记载，猪形神兽，长有利爪，叫声如狗吠，出现预示大量土木工程。
- **数值设定**：
  - **体型**：22x22 (中)
  - **HP**：60 + Level×160
  - **攻击力**：6 + Level×3
  - **移动**：中速（2）。
  - **死亡动画**：300ms。
- **攻击方式 (3 种模式)**：
  1. **土涌突刺**：在前方间隔发射火球弹（土块爆炸，呼应"土功"）。持续 1200ms，每 400ms 发射一发。
  2. **獠吠震波**：发射 5 发扇形普通子弹阵（呼应"其音如狗吠"）。持续 400ms。
  3. **穴地陷阱**：在随机位置标记 2 个陷阱，延迟 500ms 后爆炸发射火球。持续 800ms。
### 所有角色数值设计

#### 玩家 (LeadingRole) 数值公式

玩家的数值受基础属性、等级成长和 PerkCard（天赋卡）共同影响。

##### 1. 基础属性与成长

- **生命值 (HP):**
  - `MaxHealth` = 初始值 (180) + `Level`  成长 (每级+20) + `Perk: HEALTH_UP`
  - `CurrentHealth`: 升级时回满；受伤害减少；受回血机制增加。
- **攻击力 (Atk):**
  - `AttackPower` = 初始值 (15) + `Level`  成长 (每级+1) + `Perk: ATTACK_UP`
- **移动速度:**
  - `MoveSpeed` = 初始值 (1) + `Perk: MOVE_SPEED_UP`

#### 2. 战斗机制公式

- **射击冷却 (Cooldown):**
  - `冷却时间(ms)` = `shootCooldownResetTime` (4000) / shootCooldownSpeed
  - shootCooldownSpeed = 初始值 (4) + `Level`  成长 (每 5 级+2) + `Perk: ATTACK_SPEED_UP`
- **热量机制 (Heat):**
  - `热量上限` = `maxHeat` (100) + `Level`  成长 (每级+5) + `Perk: HEAT_CAPACITY_UP`
  - `冷却速率` = **每 2000ms** 结算一次，减少 `heatCoolDownRate * 10` 点热量；初始 `heatCoolDownRate = 4`，每 2 级 +1，Perk: HEAT_COOL_DOWN_UP 每张 +2。
  - `单发热量` = `heatPerShot` (初始 **15**，每 2 级 -1，最低不低于 1) × 枪械倍率（普通 1.0x / 火球 2.0x / 闪电 1.5x）。
- **回血机制 (Regen):**
  - `触发间隔` = `healResetTime` (15000) / `healSpeed` (3) = 5000ms
  - `单次回复量` = `healValue` (初始 5 + 每级+1 + `Perk: HEAL_AMOUNT_UP`)

#### 3. 玩家伤害输出公式 (createBullet)

- **普通子弹 (Basic):**  
   Damage=attackPowerDamage=attackPower
- **火球弹 (FireBall):**  
   Damage=attackPower+10Damage=attackPower+10
  _(注：火球造成一次直接伤害 + 范围伤害，两者数值相同)_
- **闪电链 (Lightning):**  
   Damage=(attackPower×multiplier)+30Damage=(attackPower×multiplier)+30
  _(注：`multiplier`  初始为 1.5，可通过 Perk 提升)_

#### 敌人 (Enemy) 数值公式

敌人的数值主要由其类型和当前游戏等级 (`Level`) 决定。

#### 1. 基础属性 (通用模板)

- **生命值 (HP):**  
   HP=BaseHP+(Level×HP_Growth)HP=BaseHP+(Level×HP_Growth)
- **攻击力 (Atk):**  
   Atk=BaseAtk+(Level×Atk_Growth)Atk=BaseAtk+(Level×Atk_Growth)
- **经验掉落 (XP):**  
   DropExp=BaseExp+(Level×Exp_Growth)DropExp=BaseExp+(Level×Exp_Growth)
- **热量冷却:** 基类同一逻辑，每 2000ms 结算一次，减少 `heatCoolDownRate * 10` 点（敌人默认 `heatCoolDownRate = 10`，见 enemyRole.cpp）。

#### 2. 具体敌人数值 (基于 enemyRole.cpp)

| 敌人类型 | 生命值公式 (HP) | 攻击力公式 (Atk) | 碰撞伤害 | 备注 |
| :--- | :--- | :--- | :--- | :--- |
| **飞廉 (Feilian)**  | 10 + Level×20 | 2 + Level×1 | 4 + Level×1 | 高速骚扰，低伤脆皮 |
| **蛊雕 (Gudiao)** | 20 + Level×150 | 8 + Level×2 | 4 + Level×1 | 远程伏击，死后发火球 |
| **魑魅 (ChiMei)** | 1 + Level×1 | 1 + Level×1 | 20（固定） | 自爆冲撞 |
| **驳 (Bo)** | 40 + Level×200 | 6 + Level×2 | 10 + Level×3 | 精英，冲锋/扇形射击 |
| **胜遇 (Shengyu)**  | 50 + Level×220 | 10 + Level×4 | 6 + Level×2 | 精英，水雾干扰/洪波 |
| **狸力 (Lili)** | 60 + Level×160 | 6 + Level×3 | 8 + Level×2 | 精英，土涌/陷阱 |
| **饕餮 (Taotie)** | 50 + Level×1700 | 2 + Level×4 | 10 + Level×10 | BOSS，吞噬/冲撞/碾压 |
| **梼杌 (Taowu)** | 30 + Level×1200 | 10 + Level×6 | 7 + Level×5 | BOSS，闪现/弹幕爆发 |
| **相柳 (Xiangliu)** | 30 + Level×1300 | 3 + Level×5 | 12 + Level×4 | BOSS，全屏AOE/召唤 |
| **混沌 (Hundun)** | 40 + Level×1400 | 8 + Level×6 | 15 + Level×8 | BOSS（四凶之首），混乱弹幕 |

#### 3. 敌人伤害输出

- **普通射击:**  造成  `Atk`  点伤害。
- **碰撞伤害:**  等于其  `collisionPower`。
- **特殊技能:**  如火球或闪电，遵循与玩家相同的伤害增幅逻辑（例如火球通常比普攻高）。

#### 通用物理与状态公式

适用于所有角色（玩家与敌人）：

- **移动公式:**  
   NewPos=CurrentPos+(Direction×Speed)NewPos=CurrentPos+(Direction×Speed)
- **碰撞回退:** BackStep=BaseStep×ConsecutiveCollisionCountBackStep=BaseStep×ConsecutiveCollisionCount
  _(注：连续碰撞次数越多，弹开距离越远，防止卡死)_
- **受伤公式:** CurrentHealth=max⁡(0,CurrentHealth−Damage)CurrentHealth=max(0,CurrentHealth−Damage)

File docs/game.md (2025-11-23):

1. 回复速度提升 +2   //2张
2. 回复量提升 +5    //2张
3. 生命值提升 +100   //2张
4. 攻击力提升 +5     //2张
5. 攻击速度提升 +3   //2张
6. 热量上限    +25   //2张
7. 热量冷却量   +2   //2张
6. 解锁火球弹        //1张
7. 解锁闪电弹        //1张
8. 火球弹范围增大 +5 //2张
9. 闪电弹倍率提升 +1.5 //2张
10. 神速：移动速度+1   //1张

//每升两级给一张强化卡
//5
//新手关卡通过给一张强化卡
//1
//每一个章节，打完一个精英关卡给一张，打完BOSS关卡给一张
//6

//打完后，最后一个是高数值挑战关

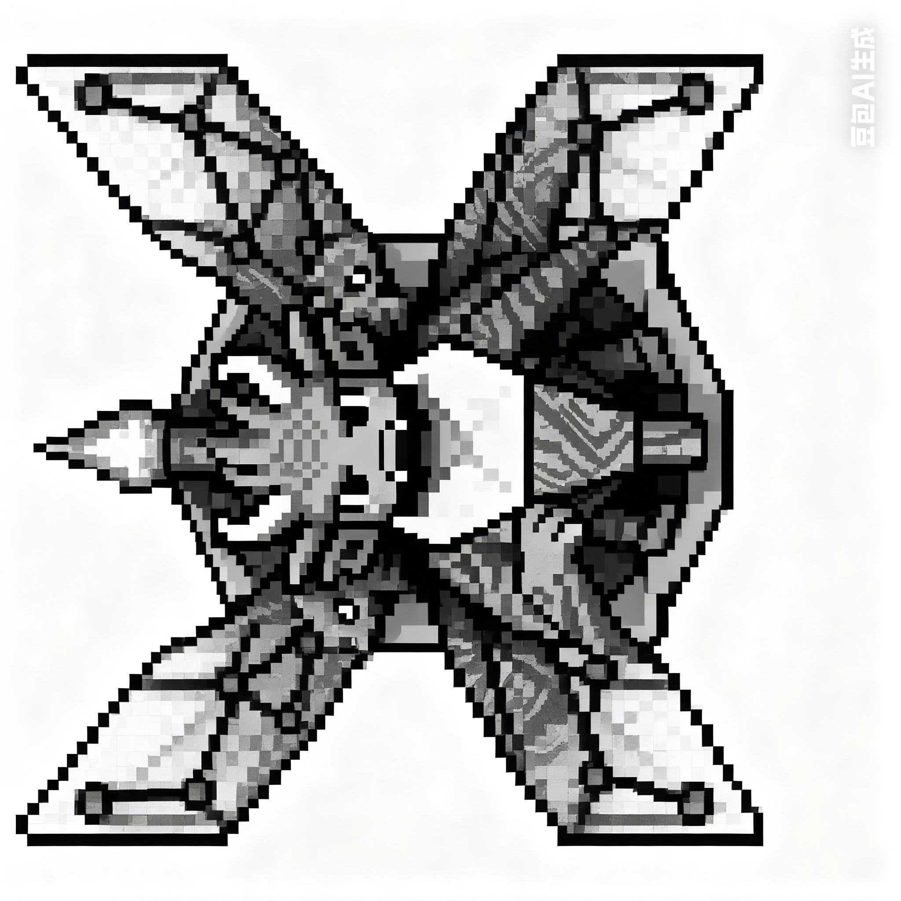
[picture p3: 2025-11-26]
ChipTanksPic/Taowu.png

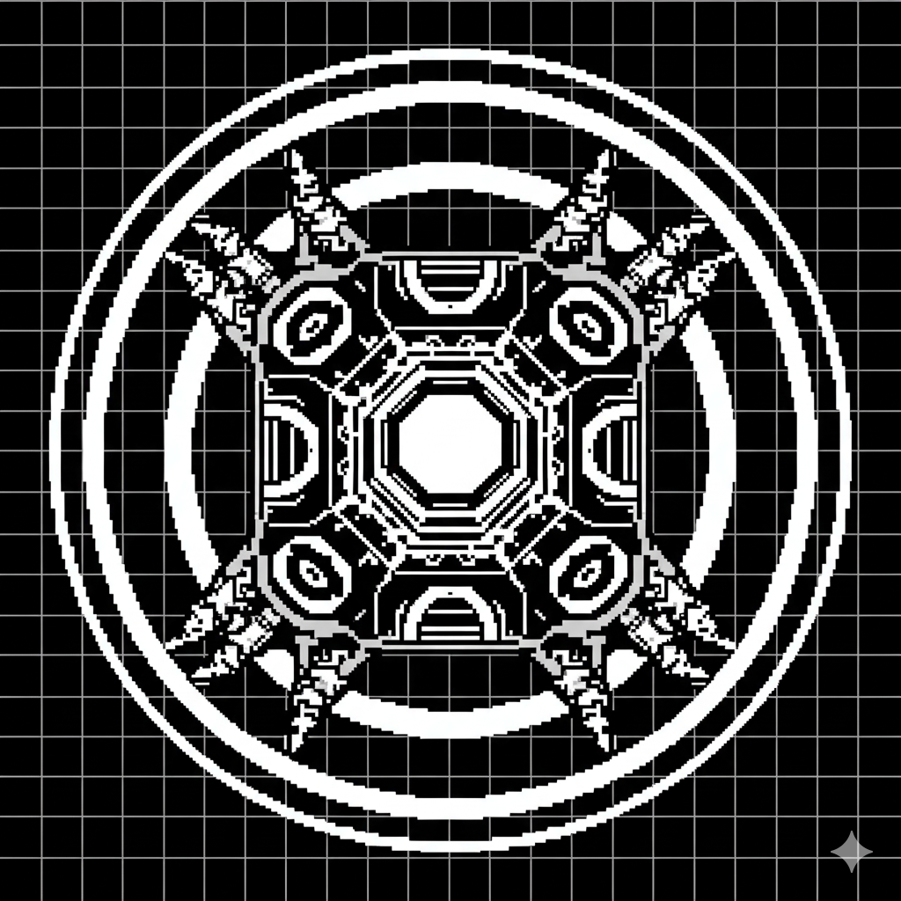
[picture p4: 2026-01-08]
ChipTanksPic/Lili.png

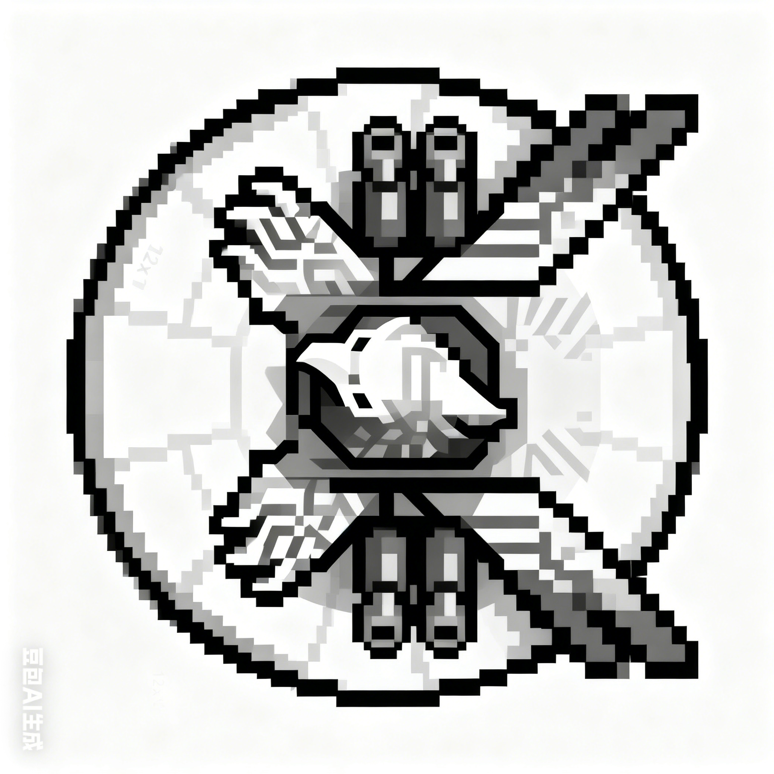
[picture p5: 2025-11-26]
ChipTanksPic/Gudiao.png

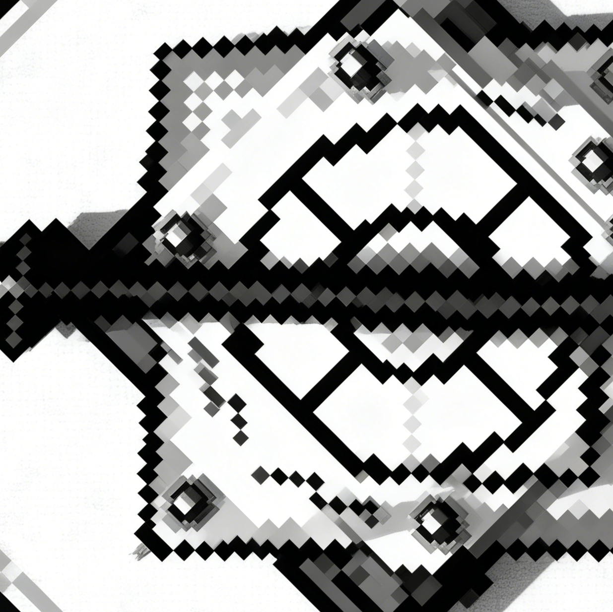
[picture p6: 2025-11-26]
ChipTanksPic/Chi-Mei.png

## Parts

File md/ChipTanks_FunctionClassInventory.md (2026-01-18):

# ChipTanks 项目 - 主要类与函数清单

## 表1 核心游戏类

| 类名称 | 主要功能 | 说明 |
|---|---|---|
| **IRole** | 角色抽象基类 | 所有角色(玩家、敌人)的抽象接口，定义虚函数：`init()`、`think()`、`doAction()`、`drawRole()`、`die()`、`shoot()`、`move()`、`takeDamage()`等 |
| **LeadingRole** | 玩家角色 | 主角坦克，继承IRole，实现玩家操控逻辑、射击机制、碰撞判定 |
| **FeilianEnemy** | 飞廉敌人 | 小型高速敌人(12x12像素)，风神形象，发射普通子弹，群体压迫 |
| **GudiaoEnemy** | 蛊雕敌人 | 中型敌人(15x15像素)，山海经猛禽，高伤害普通子弹，两侧射击，死亡发火球 |
| **ChiMeiEnemy** | 魑魅敌人 | 小型高速敌人(8x8像素)，自杀式冲撞，山林妖怪 |
| **BoEnemy** | 驳精英敌人 | 中型精英敌人(24x24像素)，三种攻击模式：冲锋践踏(MODE_1)、虎牙利爪(MODE_2)、鼓音震荡(MODE_3) |
| **ShengyuEnemy** | 胜遇精英敌人 | 中型干扰型敌人，三种攻击模式：水雾弥漫(MODE_1)、洪波推涌(MODE_2)、赤羽雷鸣(MODE_3)，以干扰视线为主 |
| **LiliEnemy** | 狸力精英敌人 | 中型精英敌人，三种攻击模式：土涌突刺(MODE_1)、獠吠震波(MODE_2)、陷阱伏击(MODE_3) |
| **TaotieEnemy** | 饕餮BOSS敌人 | 大型BOSS敌人，贪食凶兽，复杂AI和多种攻击模式 |
| **TaowuEnemy** | 肉BOSS敌人 | 大型BOSS敌人，肉形凶兽，高血量高伤害 |
| **XiangliuEnemy** | 相柳BOSS敌人 | 大型BOSS敌人，多头蛇形凶兽，复杂多段攻击模式 |
| **HundunEnemy** | 混沌BOSS敌人 | 大型终极BOSS敌人，终极凶兽，最强AI和最复杂攻击模式 |

## 表2 子弹系统类

| 类名称 | 主要功能 | 说明 |
|---|---|---|
| **IBullet** | 子弹抽象基类 | 所有子弹的抽象接口，定义虚函数：`update()`、`draw()`、`isActive()`、`getCollisionBox()`等 |
| **BasicBullet** | 普通子弹 | 标准直线运动子弹，命中敌人或边界消失，造成attackPower伤害 |
| **FireBall** | 火球弹 | 范围伤害子弹，击中目标后造成中心伤害+范围伤害(attackPower+10) |
| **LightningLine** | 闪电链弹 | 穿透伤害子弹，一束范围伤害(mul×attackPower+30)，带视觉效果 |

## 表3 游戏管理类

| 类名称 | 主要功能 | 说明 |
|---|---|---|
| **GameEntityManager** | 实体管理器 | 管理游戏中所有角色和子弹，提供添加/删除/获取实体、碰撞检测、批量更新等功能 |
| **GameProgressManager** | 进度管理器 | 管理游戏进度、波次生成、难度曲线、得分统计、游戏状态转换(初始化/进行/暂停/结束) |
| **GamePerkCardManager** | 卡牌管理器 | 管理游戏中的增益卡(Perk Card)系统，提供卡牌生成、选择、效果应用等功能 |

## 表4 核心虚函数(IRole接口)

| 函数名称 | 主要功能 | 调用时机 |
|---|---|---|
| **init()** | 初始化角色 | 角色创建后立即调用，执行缓慢进场动画 |
| **think()** | AI决策逻辑 | 每帧调用(约10ms)，根据当前状态和环境决定下一步行动 |
| **doAction()** | 执行动作 | 每帧调用，执行think()决定的动作(移动、射击、特殊技能等) |
| **drawRole()** | 绘制角色 | 每帧调用，将角色图像绘制到OLED屏幕 |
| **die()** | 死亡处理 | 角色血量≤0时调用，执行死亡动画和掉落物品等 |
| **shoot()** | 发射子弹 | 由doAction()调用，根据BulletType创建子弹并加入管理器 |
| **move()** | 移动角色 | 由doAction()调用或AI系统调用，移动角色同时处理碰撞 |
| **takeDamage()** | 受伤处理 | 被子弹击中时调用，扣血并应用伤害效果 |
| **update()** | 更新状态 | 每帧调用(由GameEntityManager调用)，更新冷却、热量、计时器等 |

## 表5 主要游戏数据结构

| 数据结构 | 主要功能 | 包含内容 |
|---|---|---|
| **RoleData** | 角色基础数据容器 | healthData(血量)、attackData(攻击)、spatialData(位置)、heatData(热量)、deathData(死亡)、actionData(动作)等 |
| **HealthData** | 血量系统 | 当前血量、最大血量、回血信息、受伤计时器 |
| **AttackData** | 攻击系统 | 攻击力、射击冷却、子弹速度、子弹范围、伤害倍率、碰撞伤害 |
| **SpatialData** | 空间信息 | 当前位置、参考位置、大小、移动速度、边界处理 |
| **HeatData** | 热量系统(玩家) | 最大热量、当前热量、单发热量消耗、冷却速率 |
| **ActionData** | 动作系统 | 当前状态(IDLE/MOVE/ATTACK等)、攻击模式(MODE_1/2/3) |
| **CollisionBox** | 碰撞体 | 矩形碰撞范围，用于碰撞检测 |

## 表6 游戏循环与控制流

| 函数/过程 | 主要功能 | 说明 |
|---|---|---|
| **main()** | 主函数 | STM32 HAL库初始化后的主程序入口，启动FreeRTOS多线程 |
| **gameLoopTask()** | 游戏主循环 | FreeRTOS任务(threads.cpp)，约10ms周期执行一次，调度游戏逻辑更新 |
| **gameUpdateTask()** | 游戏更新 | FreeRTOS任务，更新所有角色和子弹状态，检测碰撞，管理游戏进度 |
| **gameDrawTask()** | 游戏绘制 | FreeRTOS任务，每帧调用所有角色的drawRole()并更新OLED显示 |
| **controlDelayTime** | 控制周期 | 全局变量(10ms)，定义游戏逻辑更新时间间隔 |

## 表7 输入输出接口

| 函数名称 | 主要功能 | 说明 |
|---|---|---|
| **OLED_DrawImage()** | 绘制图像 | 在OLED屏幕指定坐标绘制图片 |
| **OLED_DrawLine()** | 绘制直线 | 绘制视觉效果线条(如冲锋轨迹、射线等) |
| **OLED_DrawRectangle()** | 绘制矩形 | 绘制矩形(如迷雾效果、UI边框等) |
| **OLED_ShowString()** | 显示文本 | 在屏幕显示ASCII字符(如得分、生命值等) |
| **key_scan()** | 按键扫描 | 物理按键输入处理，检测玩家操作(上下左右、射击等) |
| **getPlayerRole()** | 获取玩家 | GameEntityManager提供，获取当前玩家角色指针 |
| **getAllRoles()** | 获取所有角色 | GameEntityManager提供，遍历所有角色列表 |
| **getAllBullets()** | 获取所有子弹 | GameEntityManager提供，遍历所有子弹列表 |

## 表8 游戏参数系统

| 系统名称 | 主要参数 | 说明 |
|---|---|---|
| **冷却系统** | shootCooldownResetTime / shootCooldownSpeed | 射击冷却计算：冷却时间(ms) = resetTime / speed |
| **热量系统(玩家)** | maxHeat / heatPerShot / heatCoolDownRate | 热量管理，限制玩家连续射击，冷却周期约2000ms |
| **伤害系统** | attackPower / bulletDamageMultiplier / collisionPower | 多层伤害机制(基础伤害+倍率+碰撞伤害) |
| **子弹热量消耗** | 普通子弹×1 / 火球弹×2 / 闪电链×1.5 | 不同子弹类型的热量成本 |
| **波次生成** | 敌人数量 / 敌人类型 / 难度等级 | 根据游戏进度动态生成敌人波次 |
| **死亡动画时间** | 各敌人DeadTime常数(250-500ms) | 角色死亡后的动画持续时间 |

## 表9 STM32 HAL外设接口

| 外设接口 | 主要功能 | 说明 |
|---|---|---|
| **SSD1306 OLED** | 图形显示 | 128×64像素显示屏，显示游戏画面、UI信息 |
| **GPIO(按键)** | 输入控制 | 物理按键采集，玩家操作输入(上下左右移动、射击) |
| **I2C** | 通讯接口 | OLED屏幕通讯协议 |
| **systick/Timer** | 时基/中断 | FreeRTOS心跳、定时事件、精确延时(controlDelayTime) |
| **UART/SPI** | 串口通讯 | 可选扩展(调试输出、无线通讯等) |

---

## 游戏流程图

```
初始化 → FreeRTOS启动多任务 → 游戏循环(10ms周期)
    ↓                              ↓
 HAL初始化              ┌─────────┼──────────┐
 OLED初始化             │         │          │
 GPIO初始化        gameLoopTask gameUpdate gameDrawTask
 按键初始化             │    Task    Task     │
 系统时钟配置           └─────────┼──────────┘
                                 ↓
                       更新角色→检测碰撞→绘制→游戏结束判定
```

## 关键设计特点

1. **多继承架构**: 所有角色通过IRole接口实现统一的行为规范
2. **分离渲染**: drawRole()独立一个任务，确保绘制流畅
3. **热量限制**: 玩家热量系统平衡游戏难度，防止过度连射
4. **AI分层**: 普通敌人简单逻辑，精英敌人中等复杂度，BOSS极高复杂度
5. **FreeRTOS多任务**: 并发处理游戏逻辑、输入采集、显示刷新
6. **神话元素**: 敌人设计基于中国古代山海经神话设定，各具特色

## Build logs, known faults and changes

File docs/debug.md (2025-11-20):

# C++ & FreeRTOS 嵌入式项目编译错误排查总结

本文档总结了在 `ChipTanks` 项目开发过程中遇到的几个典型编译与链接问题，旨在深入分析错误根源，理解其底层原理，并为未来开发提供规避错误的最佳实践。

---

## 1. 链接器错误: `undefined reference to 'vtable for ...'`

### 现象

代码编译（compilation）过程顺利通过，但在最后的链接（linking）阶段失败，并报告类似如下的错误：

```
ld.exe: ... undefined reference to `vtable for FeilianEnemy'
collect2.exe: error: ld returned 1 exit status
```

### 问题分析与原理

- **什么是虚函数表 (vtable)?**
  在 C++ 中，当一个类拥有虚函数（或继承自一个有虚函数的基类）时，编译器会为这个类创建一个“虚函数表”（vtable）。vtable 本质上是一个函数指针数组，存储了该类所有虚函数的实际地址。当通过基类指针调用虚函数时，程序会通过对象的 vtable 查找到正确的派生类函数来执行，从而实现多态。

- **vtable 在哪里生成?**
  C++ 标准没有硬性规定，但主流编译器（如 GCC/G++）通常遵循一个通用实践：**将一个类的 vtable 放在包含了该类第一个非内联（non-inline）虚函数定义的那个目标文件（`.obj`）中。**

- **出错原因**
  链接器在整合所有目标文件（`.obj`）以创建最终可执行文件时，找不到 `FeilianEnemy` 类的 vtable。根据上述原理，这意味着**没有任何一个被链接的目标文件包含了 `FeilianEnemy` 类中任何一个虚函数的实现代码**。

  在我们的项目中，`FeilianEnemy` 继承自 `IRole`，因此拥有虚函数。我们将 `shoot()` 方法的实现从头文件 `enemyRole.hpp` 移到了源文件 `enemyRole.cpp` 中。然而，新创建的 `enemyRole.cpp` 文件**没有被添加到 `CMakeLists.txt` 的编译列表里**。因此，构建系统从未编译过 `enemyRole.cpp`，也就没有生成包含 vtable 的 `enemyRole.cpp.obj` 文件。链接器自然就找不到它所需要的 vtable。

### 解决方案与如何避免

- **解决方案:**
  编辑项目根目录下的 `CMakeLists.txt` 文件，将新创建的 `.cpp` 文件（如 `App/Role/enemyRole.cpp`）添加到 `add_executable` 或 `target_sources` 的源文件列表中。

  ```cmake
  add_executable(ChipTanks
      # ... 其他源文件
      App/Role/enemyRole.cpp  # <-- 确保实现虚函数的源文件被添加
  )
  ```

- **如何避免:**
  养成习惯：当为一个类（尤其是包含虚函数的类）创建 `.cpp` 实现文件时，必须**立即**将其添加到项目的构建配置（如 `CMakeLists.txt` 或 Makefile）中。

---

## 2. 编译错误: 头文件循环引用 (Include Hell)

### 现象

编译时出现大量错误，通常是以下几种情况的组合：
- "Redefinition of 'class...'" (类重定义)
- "Unknown type name..." (未知类型名)
- "'ClassName' has incomplete type" ('ClassName' 是不完整类型)

### 问题分析与原理

当两个或多个头文件形成了相互包含的闭环时，就会发生循环引用。

**示例:**
1.  `enemyRole.hpp` 为了调用实体管理器的功能，需要 `#include "gameEntityManager.hpp"`。
2.  `gameEntityManager.hpp` 为了管理所有角色，需要知道 `IRole` 的定义，因此 `#include "role.hpp"`。而为了了解具体的敌人类型，它可能还想 `#include "enemyRole.hpp"`。

这就形成了 `enemyRole.hpp` -> `gameEntityManager.hpp` -> `enemyRole.hpp` 的依赖循环。

即使有 `#ifndef` / `#define` / `#endif` 或 `#pragma once` 这样的“头文件卫士”，也无法完全解决问题。卫士只能防止同一个文件在**一次编译中**被重复展开，但无法解决“不完整类型”问题。在循环引用中，一个类可能在另一个类需要其完整定义（如访问成员函数）时，自身还未被完全解析，编译器此时只知道它是个“不完整类型”，从而报错。

### 解决方案与如何避免

核心思想是**解耦**，打破依赖循环。

1.  **使用前向声明 (Forward Declaration):**
   在头文件（`.hpp`）中，如果只需要一个类的**指针或引用**，而不需要访问其内部成员或了解其大小时，就不要包含其完整头文件。只需使用 `class ClassName;` 进行前向声明即可。

   **示例 (enemyRole.hpp):**
   ```cpp
   // #include "gameEntityManager.hpp" // 不要这样做
   class GameEntityManager; // 这样做
   extern GameEntityManager g_entityManager;
   ```

2.  **将实现代码分离到源文件 (.cpp):**
   将那些需要使用被前向声明的类的完整定义（例如，调用其成员函数）的代码，从头文件（`.hpp`）中移动到对应的源文件（`.cpp`）中。

3.  **在源文件中包含完整头文件:**
   在 `.cpp` 文件中，可以安全地包含所有需要的头文件（如 `gameEntityManager.hpp`），因为 `.cpp` 文件是编译的终点，不会再被其他文件包含，不会延续依赖链。

- **如何避免:**
  - 遵循**“最小包含原则”**：在头文件中，只包含绝对必要的东西。
  - 优先使用前向声明，而不是直接 `#include`。
  - 将类的实现细节（成员函数的定义）严格地放在 `.cpp` 文件中，保持 `.hpp` 文件只作为接口声明。

---

## 3. 编译错误: FreeRTOS 头文件包含顺序

### 现象

编译时出现明确的预处理错误，以及大量关于 FreeRTOS 类型未定义的错误：

```
#error "include FreeRTOS.h must appear in source files before include task.h"
'TickType_t' does not name a type
'BaseType_t' does not name a type
...
```

### 问题分析与原理

这是 FreeRTOS 的一个硬性规定。`FreeRTOS.h` 文件是整个系统的核心，它定义了所有其他组件所依赖的基础数据类型（如 `TickType_t`, `BaseType_t`）、宏和全局配置。

其他 FreeRTOS 头文件（如 `task.h`, `queue.h`, `semphr.h`）在内部都使用了这些基础类型。如果在包含它们之前没有先包含 `FreeRTOS.h`，这些类型对于编译器来说就是未知的，从而导致编译失败。`task.h` 等文件内部的 `#error` 指令就是为了强制开发者遵循这个规则，以便在第一时间发现问题。

在我们的项目中，`gameEntityManager.hpp` 文件包含了 `task.h`，但在它之前没有包含 `FreeRTOS.h`，导致任何包含了 `gameEntityManager.hpp` 的 `.cpp` 文件都会触发这个错误。

### 解决方案与如何避免

- **解决方案:**
  在任何需要包含 FreeRTOS 组件头文件（如 `task.h`）的地方，**首先确保 `FreeRTOS.h` 已经被包含**。最稳妥的做法是在那个头文件内部就修正顺序。

  **示例 (gameEntityManager.hpp):**
  ```cpp
  // ...
  #include "FreeRTOS.h" // 确保这一行在 task.h 之前
  #include "task.h"
  // ...
  ```

- **如何避免:**
  - 将 FreeRTOS 的头文件包含顺序作为一个编码规范。
  - 当创建一个需要使用 FreeRTOS 功能的模块（如一个类）时，在该模块的头文件中就处理好 `FreeRTOS.h` 的包含顺序，而不是把这个责任推给使用该模块的调用者。
  - 在项目的全局配置文件（如 `stdafx.h` 或 `main.h`）中优先包含 `FreeRTOS.h` 也是一种常见的策略。

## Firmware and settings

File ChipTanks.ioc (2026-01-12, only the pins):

Mcu.UserName=STM32F103C8Tx
PA0-WKUP.GPIO_Label=KEY_R1
PA0-WKUP.Signal=GPIO_Input
PA1.GPIO_Label=KEY_R2
PA1.Signal=GPIO_Input
PA13.Signal=SYS_JTMS-SWDIO
PA14.Signal=SYS_JTCK-SWCLK
PA2.GPIO_Label=KEY_R3
PA2.Signal=GPIO_Input
PA3.GPIO_Label=KEY_R4
PA3.Signal=GPIO_Input
PA4.GPIO_Label=KEY_C1
PA4.Signal=GPIO_Input
PA5.GPIO_Label=KEY_C2
PA5.Signal=GPIO_Input
PA6.GPIO_Label=KEY_C3
PA6.Signal=GPIO_Input
PA7.GPIO_Label=KEY_C4
PA7.Signal=GPIO_Input
PB6.Signal=I2C1_SCL
PB7.Signal=I2C1_SDA
PD0-OSC_IN.Signal=RCC_OSC_IN
PD1-OSC_OUT.Signal=RCC_OSC_OUT

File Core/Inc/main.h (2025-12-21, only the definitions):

#define KEY_R1_Pin GPIO_PIN_0
#define KEY_R1_GPIO_Port GPIOA
#define KEY_R2_Pin GPIO_PIN_1
#define KEY_R2_GPIO_Port GPIOA
#define KEY_R3_Pin GPIO_PIN_2
#define KEY_R3_GPIO_Port GPIOA
#define KEY_R4_Pin GPIO_PIN_3
#define KEY_R4_GPIO_Port GPIOA
#define KEY_C1_Pin GPIO_PIN_4
#define KEY_C1_GPIO_Port GPIOA
#define KEY_C2_Pin GPIO_PIN_5
#define KEY_C2_GPIO_Port GPIOA
#define KEY_C3_Pin GPIO_PIN_6
#define KEY_C3_GPIO_Port GPIOA
#define KEY_C4_Pin GPIO_PIN_7
#define KEY_C4_GPIO_Port GPIOA

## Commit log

2025-11-17 初始化项目
2025-11-19 完成基本框架，完成Feilian的编写，完成player的编写，碰撞模块处理完成
2025-11-19 修改项目基本信息
2025-11-20 敌人子弹设计功能实现，考虑hpp与cpp分离
2025-11-20 敌我的子弹射击功能实现，添加回血的机制
2025-11-21 子弹功能和撞击功能完善，死亡动画留出接口，封装绘制角色接口，封装绘制子弹接口
2025-11-22 完成所有敌人的基本代码框架编写，完成饕餮的基本代码，修补连续碰撞无法正确处理的bug
2025-11-22 完成BOSS饕餮的设计
2025-11-22 保存一版代码，开始写BOSS梼杌
2025-11-22 完成BOSS梼杌设计，测试通过
2025-11-22 完成BOSS相柳的基本框架编写
2025-11-22 完成BOSS相柳设计，但有bug，更改梼杌部分机制
2025-11-23 完成BOSS相柳的bug修复，完成主角的升级功能
2025-11-23 做实验去了，保存一下这版bug代码
2025-11-23 保存目前可以显示的perkManager代码，在选卡时有bug
2025-11-23 基本完成PerkCardManager的编写，但有显示错误的bug
2025-11-23 目前除了perkCard的显示bug，其余均已修复，开始编写gameProgressManager并进行整合测试
2025-11-23 需要修复Perk显示错误的bug，基本完成游戏流程框架控制
2025-11-23 简单保存一版，明天再战
2025-11-24 基本完成所有功能，还缺一个暂停,，以及perkSelection的显示bug没修
2025-11-24 修改部分意料之外的bug（结束动画播放异常），美化开场播放动画，还差Perk显示异常
2025-11-24 修改最后挑战关波次错误的bug
2025-11-24 保存一版
2025-11-24 修复显示bug
2025-11-24 最终的完成版本v1.0
2025-11-24 最终完成版本v1.01
2025-11-24 修复之前改完显示bug后多删了一行代码的问题
2025-11-24 完成的稳定版本v1.1
2025-11-24 添加第四关警告，修改BOSS出场位置
2025-11-24 修改第四关警告
2025-11-25 添加主角死亡后的提示和动画，修复死亡动作重复执行两次的bug
2025-11-26 将图片库添加，修改主角死亡动画时间
2025-11-26 删除一些无用的文件
2025-11-27 添加统计代码状态的脚本
2025-11-27 修改一下格式错误
2025-11-27 整理一下文件夹
2025-11-27 添加readme
2025-11-27 添加博客地址
2025-12-01 修改第四关挑战关卡CG显示错误的bug
2025-12-15 保存一版代码
2025-12-21 适配新的硬件
2025-12-21 添加暂停功能，优化开场动画
2025-12-21 优化BOSS的出场海报特效
2025-12-21 优化暂停界面，增加科技感装饰
2025-12-21 修复热量机制的bug，修改热量上限强化的数值
2025-12-21 调整热量数值
2025-12-21 保存一版非常良好的代码
2025-12-22 添加项目的技术文档
2026-01-05 修改资料，添加文档
    [ChipTanks.PcbDoc]
2026-01-05 修复玩家死亡后还会触发选卡
2026-01-08 优化代码，优化梼杌的攻击速度，新增加BOSS混沌，添加调试模式
2026-01-08 完成精英怪bo的设计，完成精英怪Lili的设计
2026-01-08 完成精英怪shengyu的设计
2026-01-08 添加新卡片，增加僚机机制
2026-01-08 完成玩家特效
2026-01-08 稳定的一版
2026-01-08 修复完部分bug
2026-01-09 完美的一版
2026-01-12 修复右侧DOWN键无法触发选卡的bug
2026-01-17 优化Taotie过于不合理的攻击方式
2026-01-18 优化Taotie新技能子弹数量
2026-01-18 使用clangd
2026-02-13 更新一下文档格式
2026-02-13 修正文档内容

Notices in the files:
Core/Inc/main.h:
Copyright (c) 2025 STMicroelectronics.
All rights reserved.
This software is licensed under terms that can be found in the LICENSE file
